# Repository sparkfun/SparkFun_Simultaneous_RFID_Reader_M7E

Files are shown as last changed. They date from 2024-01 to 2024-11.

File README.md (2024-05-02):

SparkFun Simultaneous RFID Reader - M7E Hecto
============================================

[SparkFun Simultaneous RFID Reader - M7E Hecto

[*SparkFun Simultaneous RFID Reader - M7E Hecto*](https://www.sparkfun.com/products/24738)

The SparkFun Simultaneous RFID Reader - M7E Hecto features M7E-HECTO UHF RFID reader from JADAK<sup>&copy;</sup>. We loved the capabilities of the previous version of this RFID reader, the M6E, so we created this design featuring the M7E with an on-board USB-C connector and CH340C USB to UART converter to quickly connect the board to a computer and read tags with no soldering required.

Along with the USB-C connector, the Simultaneous RFID Reader 3.3V has a 0.1"-spaced PTH header for connecting it to an external converter or to a 3.3V microcontroller of your choice to use it with the SparkFun Simultaneous RFID Tag Reader Library. A 2-way switch on the board allows for easy switching between the included communication interfaces.

Repository Contents
-------------------

* **/Documents** - Datasheets, additional product information 
* **/Hardware** - Eagle design files (.brd, .sch)
* **/Production** - Production panel files (.brd)
* **/docs** - Documentation files for the SparkFun Simultaneous RFID Reader - M7E Hecto

Documentation
--------------
* **[Hookup Guide](https://sparkfun.github.io/SparkFun_Simultaneous_RFID_Reader_M7E)** - Basic hookup guide for the SparkFun Simultaneous RFID Reader - M7E Hecto.
* **[SparkFun Simultaneous RFID Tag Reader Library](https://github.com/sparkfun/SparkFun_Simultaneous_RFID_Tag_Reader_Library)** - Arduino library for SparkFun Simultaneous RFID Readers.

Product Versions
----------------
* [WRL-24738](https://www.sparkfun.com/products/24738) - Initial release

License Information
-------------------

This product is _**open source**_! 

Please review the LICENSE.md file for license information. 

If you have any questions or concerns on licensing, please contact technical support on our [SparkFun forums](https://forum.sparkfun.com/viewforum.php?f=152).

Distributed as-is; no warranty is given.

- Your friends at SparkFun.

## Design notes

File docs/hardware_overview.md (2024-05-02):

---
icon: material/cog
---

In this section we'll take a closer look at the hardware present on the Simultaneous RFID Reader 3.3V.

## M7E Hecto UHF RFID Reader

The M7E Hecto is an Ultra-High Frequency (UHF) RFID reader capable of reading multiple tags simultaneously at up to 150 tags per second. 

<figure markdown>
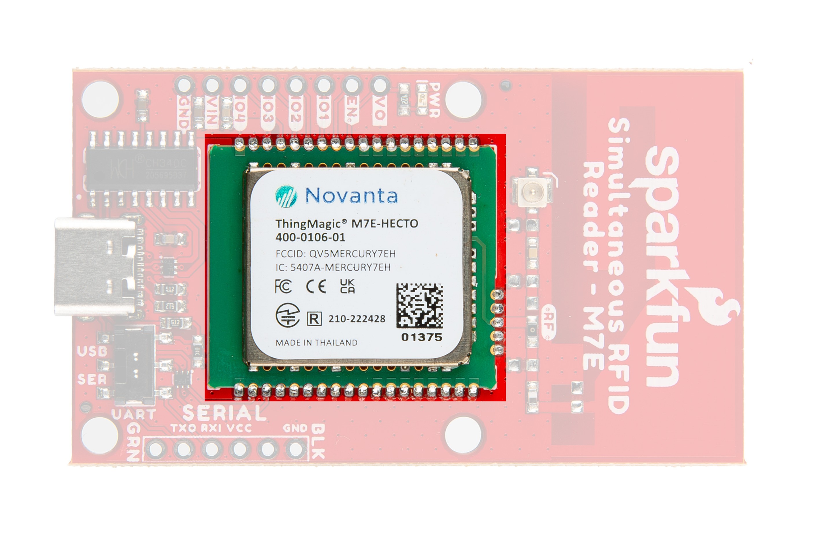
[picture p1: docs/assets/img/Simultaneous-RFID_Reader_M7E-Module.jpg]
Photo highlighting the M7E Hecto

</figure>

The module can also write data quickly to RFID tags with 96-bit EPC (80msec typical write time). The M7E Hecto boasts adjustable read and write RF power levels from 0dBm to 27dBm in 0.01dBm steps and can read tags from several feet away (even more than 16 feet in our testing!) with the proper antenna, conditions and device settings. The M7E-Hecto works with common, low-cost, passive, Gen2 UHF tags available from a variety of online vendors in a variety of shapes and sizes. We offer two types of UHF tags, ones [with adhesive](https://www.sparkfun.com/products/20228) backing and [ultra-small](https://www.sparkfun.com/products/16464) ones. Both have 64 bytes of user-writable memory.

The M7E accepts a supply voltage between <b>3.3V</b> and <b>5.5V</b> and operates normally so long as the module's current draw is below <b>1A</b> as it includes a built-in protection circuit that allows no more than <b>1A</b> drawn to prevent damage to the M7E. Therefore, it's recommended to power the M7E with a 5V source to avoid hitting the current limit at higher read/write powers or when the GPIO and Vout lines are supplying current to other devices. Refer to section 5.2 of the [M7E User Guide](./assets/component_documentation/M7E_HECTO_User_Guide.pdf) for detailed information on this limit as well as graphs showing typical current draw at various supply voltages as well as power requirements for different power settings.

## Communication Interfaces

The board has two options for interacting with the M7E Hecto's serial interface: USB-C and a plated through-hole (PTH) header. The PTH header can connect to a microcontroller or serial converter (running at <b>3.3V</b> logic or properly level-shifted). The selection switch on the board labeled <b>UART</b> allows users to choose between the two serial interface options. The board also breaks out several of the M7E Hecto's GPIO pins and the Enable pin.

<figure markdown>
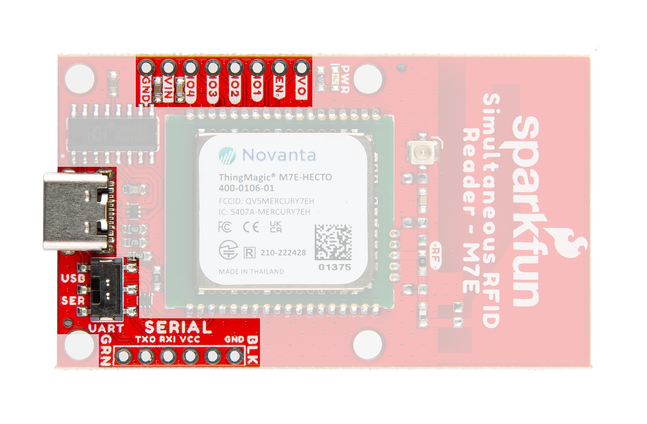
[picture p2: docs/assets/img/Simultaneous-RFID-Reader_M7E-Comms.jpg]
Photo highlighting USB, PTHs and UART Switch.

</figure>

### USB-C

The USB-C connector on the board allows for quick use of the M7E Hecto with just a USB-C cable. The board uses a CH340C USB-to-Serial adapter to translate between the M7E's UART and the USB-C connection. 

<div class="alert alert-warning">
    <b>Heads Up!</b> With RF power level set to 27dBm the board can draw over <b>700mA (3.6W @ 5V)</b>. Most USB ports on computers only source up to ~500mA so the board may start to brown out at power settings over 22dBm when powered from a USB port. Users who wish to set the over 22dBm should make sure their power source (either from USB-C via a power adapter or through a regulated <b>5V</b> supply to the VIN PTH pin) can source enough current to power the board. We recommend a power adapter like <a href="https://www.sparkfun.com/products/15448">this</a>.
</div>

### Through-Hole Serial Connection

The board includes a PTH header for serial communication with a 3.3V microcontroller or other device. The header matches the pinout for our [Serial Breakouts](https://www.sparkfun.com/products/15096) for easy connection to those devices.

### Serial Selection Switch

The two-way switch on the board labled <b>UART</b> allows the user to toggle between the two serial interfaces: USB-C (<b>USB</b>) and the Serial Header (<b>SER</b>).

### Enable and GPIO PTHs

The M7E uses an internal DC to DC converter to provide itself with power. When the <b>EN</b> (enable) pin is pulled low the DC/DC converter is turned off and the module does a hard reset. <b>EN</b> can be left unconnected for normal operation. 

!!! warning
    <b>Note:</b> The <b>3.3V</b> pin on this header is not intended as a power source. It connects to the <b>V_OUT</b> pin on the M7E Hecto which can only supply <b>5mA</b>. It is best used as a voltage reference.

## Power LED

The lone LED on the board indicates device power status. Users can disable this LED by severing the <b>PWR</b> jumper. The Power LED receives voltage from the <b>VOUT</b> pin on the M7E Hecto. Driving the <b>EN</b> pin low disables <b>VOUT</b> and can be used to turn this LED off.

<figure markdown>
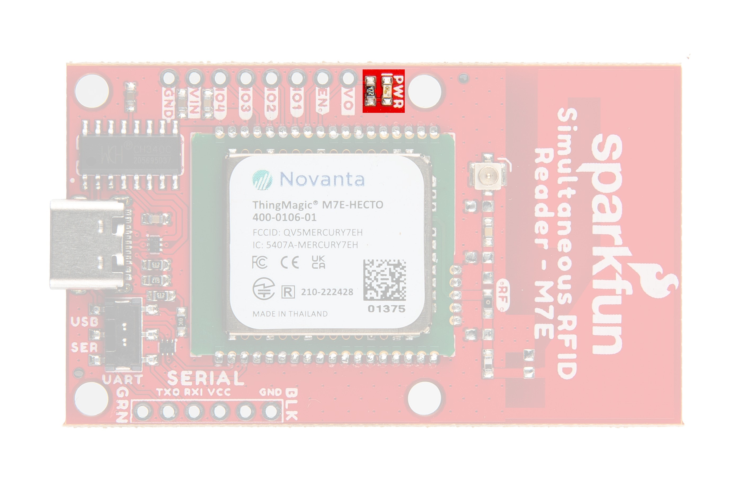
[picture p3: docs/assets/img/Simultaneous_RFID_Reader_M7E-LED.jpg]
Photo highlighting Power LED.

</figure>

## Solder Jumpers

The board has three solder jumpers labeled: <b>PWR</b>, <b>VIN SEL</b>, and <b>SHLD</b>. The table below outlines their label, function, default state, and any notes regarding their use.

<figure markdown>
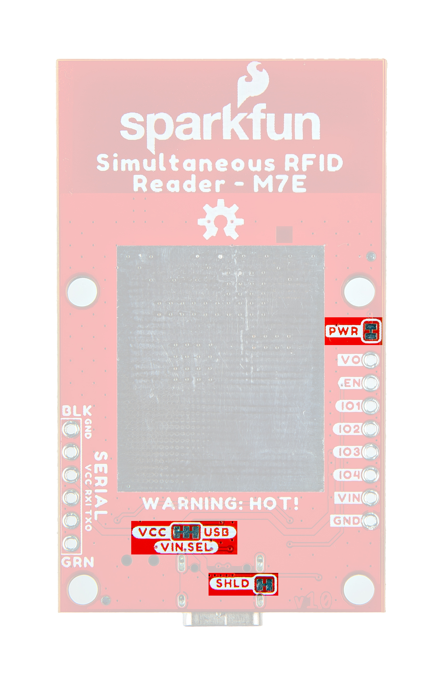
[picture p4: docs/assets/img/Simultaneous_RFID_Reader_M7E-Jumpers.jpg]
Photo highlighting solder jumpers

</figure>

<table>
    <tr>
        <th>Label</th>
        <th>Default State</th>
        <th>Function</th>
        <th>Notes</th>
    </tr>
    <tr>
        <td>PWR</td>
        <td>CLOSED</td>
        <td>Completes Power LED circuit.</td>
        <td>Open to disable Power LED.</td>
    </tr>
    <tr>
        <td>VIN SEL</td>
        <td>CLOSED</td>
        <td>Nets V_USB, VIN, and VCC together.</td>
        <td>Three-way jumper that nets all voltage inputs together. Adjust to isolate any of these voltages from the others (or all three) if needed.</td>
    </tr>
    <tr>
        <td>SHLD</td>
        <td>CLOSED</td>
        <td>Ties USB Shield pin to PCB ground plane.</td>
        <td>Open to isolate the USB Shield pin from the rest of the board.</td>
    </tr>
</table>

## Ground Plane Heatsink

The board has a large ground plane heatsink on the bottom to help dissipate heat generated by the module.

<figure markdown>
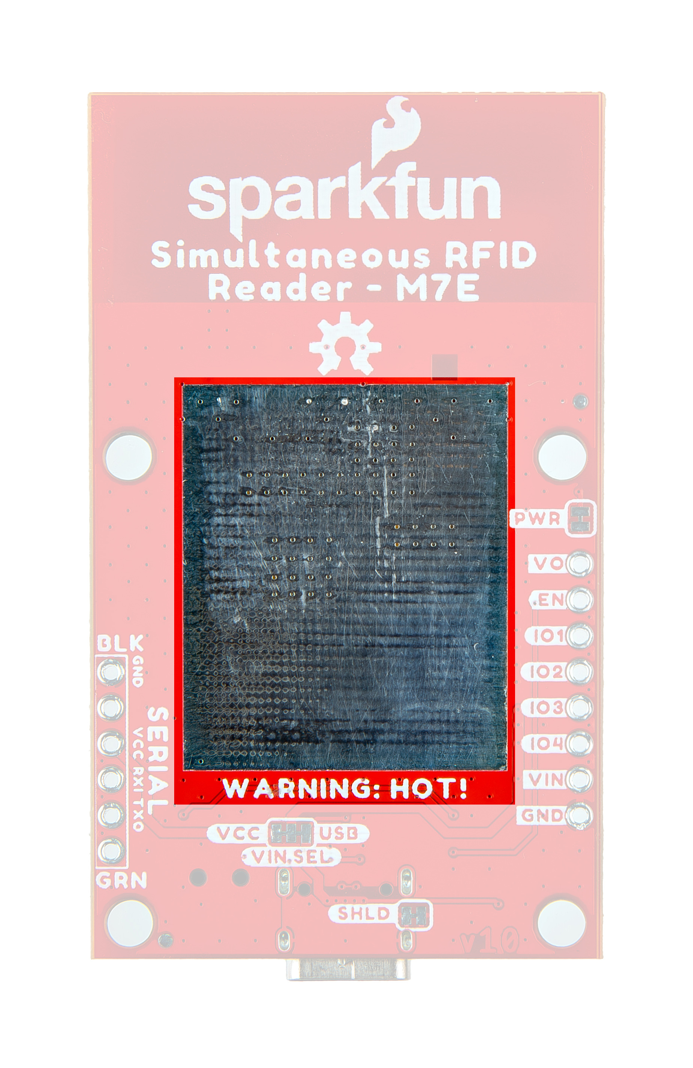
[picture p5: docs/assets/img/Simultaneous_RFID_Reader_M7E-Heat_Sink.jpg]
Photo highlighting heatsink.

</figure>

The exposed copper pour allows the connection to a heatsink such as a chassis or block of metal if needed. The M7E has an integrated temperature sensor that will monitor the internal temperature and can disable RF if the module is overheating and keeps it off until the recorded temperature drops back into the safe range (-40&deg;C to +60&deg;C). Attaching a heat sink to the exposed copper pour or adjusting the read power and/or duty cycle can help dissipate heat to prevent this throttling in long-period applications of this board. Refer to the [thermal management considerations](../thermal_management) of this guide or section 5.4 of the [M7E User Guide](./assets/component_documentation/M7E_HECTO_User_Guide.pdf) for more information.

## Antenna Options

The Hecto M7E is a powerful transmitter capable of outputting up to 27dBm! That's a lot. The board comes with a PCB trace antenna and a u.FL connector for an external antenna connection.

<figure markdown>
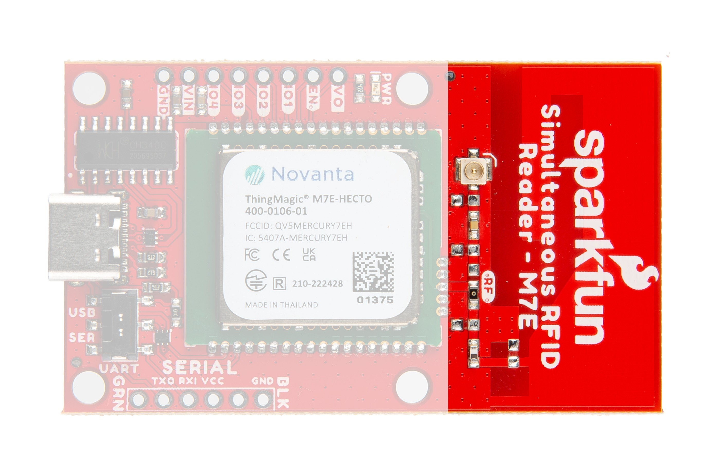
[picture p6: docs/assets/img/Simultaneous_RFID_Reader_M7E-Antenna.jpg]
Photo highlighting the PCB antenna.

</figure>

The trace antenna is enabled by default. Adjust the <b>RF</b> resistor to switch the antenna signal to the u.FL connector to use an external antenna. Refer to the [Using an External Antenna](../external_antenna) section of this guide for more information on this assembly step.

## Board Dimensions

The board measures 2.40" x 1.40" (60.96mm x 35.56mm) and has four mounting holes that fit a [4-40](https://www.sparkfun.com/products/10453) screw.

<figure markdown>
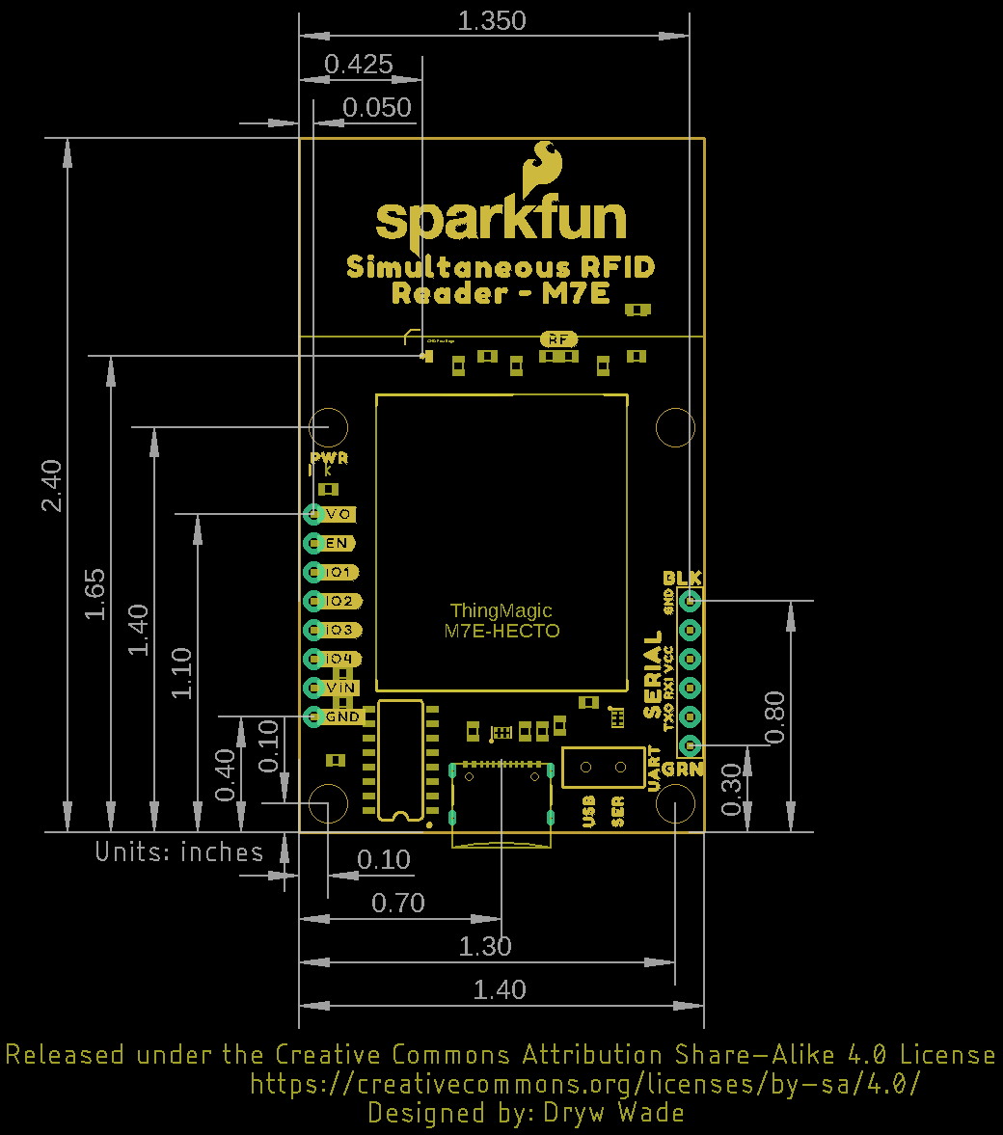
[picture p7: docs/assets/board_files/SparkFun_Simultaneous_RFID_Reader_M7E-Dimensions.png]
Board dimensions

</figure>

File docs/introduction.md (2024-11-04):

---
icon: material/book-open-page-variant
---

<div class="grid cards desc" markdown>

-   <a href="https://www.sparkfun.com/products/24738">
    **SparkFun Simultaneous RFID Reader - M7E Hecto**<br>
    **SKU:** WRL-24738

    ---

    <figure markdown>
    SparkFun Simultaneous RFID Reader - M7E Hecto
    </figure></a>

    <center>
    <article class="video_desc">
    <iframe src="https://www.youtube.com/embed/ITT54OnKUzM" title="Product Showcase: SparkFun Simultaneous RFID Reader - M7E" frameborder="0" allow="accelerometer; autoplay; clipboard-write;encrypted-media; gyroscope; picture-in-picture" allowfullscreen></iframe>
    </article>
    </center>

-   The M7E Hecto is a Ultra-High Frequency (UHF) RFID reader from JADAK<sup>&copy;</sup> capable of reading multiple tags simultaneously at up to 150 tags per second and can also write data to tags. The M7E Hecto can read tags from several feet away (up to 16 feet in our testing!) with the proper antenna, conditions and device settings. This board includes a USB-C connector and CH340C USB to UART converter to quickly connect the board to a computer and read tags with no soldering required.

    Along with the USB-C connector, the Simultaneous RFID Reader 3.3V has a 0.1"-spaced PTH header for connecting it to an external converter or to a 3.3V microcontroller of your choice to use it with the SparkFun Simultaneous RFID Tag Reader Library. A 2-way switch on the board allows for easy switching between the included communication interfaces.

    <center>
    [Purchase from SparkFun :fontawesome-solid-cart-plus:](https://www.sparkfun.com/products/24738){ .md-button .md-button--primary }
    </center>

</div>

In this guide we'll cover everything you need to set up this RFID reader and use it with the Universal Reader Assistant application to read and write to UHF tags. We'll also cover how to set this board up in a circuit with a 3.3V microcontroller and point you to where you can get started using the SparkFun Simultaneous RFID Tag Reader Arduino Library.

### Required Materials

We designed this version of the Simultaneous RFID Reader to work over either USB-C or a serial plated through-hole (PTH) connection so depending on your application, you may need different materials. 

#### USB Connection

The quickest way to get the RFID Reader up and running is through the USB-C connector. If you opt for this you'll need a USB-C cable like the ones below:

<div class="grid cards" markdown>

-   <a href="https://www.sparkfun.com/products/14743">

    <figure markdown>
    USB 3.1 Cable A to C - 3 Foot
    </figure>
    </a>
    ---
    <a href="https://www.sparkfun.com/products/14743">
    **USB 3.1 Cable A to C - 3 Foot**<br>
    CAB-14743
    </a>

-   <a href="https://www.sparkfun.com/products/15424">
    
    <figure markdown>
    Reversible USB A to C Cable - 2m
    </figure>
    </a>
    ---
    <a href="https://www.sparkfun.com/products/15424">
    **Reversible USB A to C Cable - 2m**<br>
    CAB-15424
    </a>

-   <a href="https://www.sparkfun.com/products/15425">

    <figure markdown>
    Reversible USB A to C Cable - 0.8m
    </figure>
    </a>
    ---
    <a href="https://www.sparkfun.com/products/15425">
    **Reversible USB A to C Cable - 0.8m**</br>
    CAB-15425
    </a>

-   <a href="https://www.sparkfun.com/products/15426">

    <figure markdown>
    Reversible USB A to C Cable - 0.3m
    </figure>
    </a>
    ---
    <a href="https://www.sparkfun.com/products/15426">
    **Reversible USB A to C Cable - 0.3m**<br>
    CAB-15426
    </a>

</div>

#### PTH Serial Connection

Users who prefer to use the PTH headers to connect to a serial converter or microcontroller will want to solder either wire or a set of header pins to the board to make connections to the external device. If you don't have wire, header pins or soldering tools you may want to add the products below to your cart:

!!! warning "Logic Levels"
    <b>Note:</b> The serial output on the Simultaneous RFID Reader - M7E  operates at <b>3.3V logic</b> so make sure the microcontroller or serial converter connected to this interface operates at <b>3.3V</b> or are properly level-shifted.

<div class="grid cards" markdown>

-   <a href="https://www.sparkfun.com/products/15096">

    <figure markdown>
    SparkFun Serial Basic Breakout - CH340C and USB-C
    </figure>
    </a>
    ---
    <a href="https://www.sparkfun.com/products/15096">
    **SparkFun Serial Basic Breakout - CH340C and USB-C**<br>
    DEV-15096
    </a>

-   <a href="https://www.sparkfun.com/products/9873">

    <figure markdown>
    SparkFun FTDI Basic Breakout - 3.3V
    </figure>
    </a>
    ---
    <a href="https://www.sparkfun.com/products/9873">
    **SparkFun FTDI Basic Breakout - 3.3V**<br>
    DEV-09873
    </a>

-   <a href="https://www.sparkfun.com/products/19177">

    <figure markdown>
    SparkFun IoT RedBoard - ESP32 Development Board
    </figure>
    </a>
    ---
    <a href="https://www.sparkfun.com/products/19177">
    **SparkFun IoT RedBoard - ESP32 Development Board**<br>
    DEV-19177
    </a>

-   <a href="https://www.sparkfun.com/products/15444">

    <figure markdown>
    SparkFun RedBoard Artemis
    </figure>
    </a>
    ---
    <a href="https://www.sparkfun.com/products/15444">
    **SparkFun RedBoard Artemis**<br>
    DEV-15444
    </a>

-   <a href="https://www.sparkfun.com/products/14456">

    <figure markdown>
    Soldering Iron - 60W (Adjustable Temperature)
    </figure>
    </a>
    ---
    <a href="https://www.sparkfun.com/products/14456">
    **Soldering Iron - 60W (Adjustable Temperature)**<br>
    TOL-14456
    </a>

-   <a href="https://www.sparkfun.com/products/9325">

    <figure markdown>
    Solder Lead Free - 100-gram Spool
    </figure>
    </a>
    ---
    <a href="https://www.sparkfun.com/products/9325">
    **Solder Lead Free - 100-gram Spool**<br>
    TOL-09325
    </a>

-   <a href="https://www.sparkfun.com/products/11375">

    <figure markdown>
    Hook-Up Wire - Assortment (Stranded, 22 AWG)
    </figure>
    </a>
    ---
    <a href="https://www.sparkfun.com/products/11375">
    **Hook-Up Wire - Assortment (Stranded, 22 AWG)**<br>
    PRT-11375
    </a>

-   <a href="https://www.sparkfun.com/products/553">

    <figure markdown>
    Break Away Male Headers - Right Angle
    </figure>
    </a>
    ---
    <a href="https://www.sparkfun.com/products/553">
    **Break Away Male Headers - Right Angle**<br>
    SKU
    </a>

</div>

#### Additional Materials

You'll also need UHF RFID tags for the M7E Hecto to read/write. For best range performance you'll need an external antenna along with the appropriate adapter cables. We'll demonstrate how to connect the external antenna using the cables listed below:

<div class="grid cards" markdown>

-   <a href="https://www.sparkfun.com/products/14131">

    <figure markdown>
    UHF RFID Antenna (RP-TNC)
    </figure>
    </a>
    ---
    <a href="https://www.sparkfun.com/products/14131">
    **UHF RFID Antenna (RP-TNC)**<br>
    WRL-14131
    </a>

-   <a href="https://www.sparkfun.com/products/18569">

    <figure markdown>
    RP-SMA to U.FL Cable - 150mm
    </figure>
    </a>
    ---
    <a href="https://www.sparkfun.com/products/18569">
    **RP-SMA to U.FL Cable - 150mm**<br>
    WRL-18569
    </a>

-   <a href="https://www.sparkfun.com/products/20226">

    <figure markdown>
    UHF RFID Tags - 30mm x 16mm (Adhesive)
    </figure>
    </a>
    ---
    <a href="https://www.sparkfun.com/products/20226">
    **UHF RFID Tags - 30mm x 16mm (Adhesive)**<br>
    WRL-20226
    </a>

-   <a href="https://www.sparkfun.com/products/14132">

    <figure markdown>
    Interface Cable for RP-TNC to RP-SMA - 1m
    </figure>
    </a>
    ---
    <a href="https://www.sparkfun.com/products/14132">
    **Interface Cable for RP-TNC to RP-SMA - 1m**<br>
    CAB-14132
    </a>

</div>

### Suggested Reading

If you aren't familiar with the following concepts, we recommend reading through these tutorials before continuing with this guide.

<div class="grid cards hide col-4" markdown align="center">

-   <a href="https://learn.sparkfun.com/tutorials/8">
    <figure markdown>
    Serial Communication
    </figure>
    </a>
    <a href="https://learn.sparkfun.com/tutorials/8">**Serial Communication**
    </a>

-   <a href="https://learn.sparkfun.com/tutorials/62">
    <figure markdown>
    Logic Levels
    </figure>
    </a>
    <a href="https://learn.sparkfun.com/tutorials/62">**Logic Levels**
    </a>

-   <a href="https://learn.sparkfun.com/tutorials/633">
    <figure markdown>
    RFID Basics
    </figure>
    </a>
    <a href="https://learn.sparkfun.com/tutorials/633">**RFID Basics**
    </a>

-   <a href="https://learn.sparkfun.com/tutorials/61">
    <figure markdown>
    Installing Arduino IDE
    </figure>
    </a>
    <a href="https://learn.sparkfun.com/tutorials/61">**Installing Arduino IDE**
    </a>

-   <a href="https://learn.sparkfun.com/tutorials/15">
    <figure markdown>
    Installing an Arduino Library
    </figure>
    </a>
    <a href="https://learn.sparkfun.com/tutorials/15">**Installing an Arduino Library**
    </a>

-   <a href="https://learn.sparkfun.com/tutorials/112">
    <figure markdown>
    Serial Terminal Basics
    </figure>
    </a>
    <a href="https://learn.sparkfun.com/tutorials/112">**Serial Terminal Basics**
    </a>

-   <a href="https://learn.sparkfun.com/tutorials/845">
    <figure markdown>
    Three Quick Tips About Using U.FL
    </a>
    <a href="https://learn.sparkfun.com/tutorials/845">**Three Quick Tips About Using U.FL**
    </a>

-   <a href="https://learn.sparkfun.com/tutorials/664">
    <figure markdown>
    How to Work with Jumper Pads and PCB Traces
    </figure>
    </a>
    <a href="https://learn.sparkfun.com/tutorials/664">**How to Work with Jumper Pads and PCB Traces**
    </a>
</div>

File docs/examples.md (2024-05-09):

---
icon: simple/arduino
---

Let's take an in-depth look at most of the examples included in the SparkFun Simultaneous RFID Reader Arduino Library.

## UART Switch Position & Software Serial

Make sure the Serial Selection Switch is in the <b>"SER"</b> position when using this library. All of the examples in this Arduino library use the [Software Serial Library](https://docs.arduino.cc/learn/built-in-libraries/software-serial/) so if you are not using the SparkFun RedBoard IoT and following the assembly instructions in the Hardware Assembly section, make sure to connect the RX/TX pins on the SER header to compatible pins on your chosen development board. Note, this library 

## Code to Note

The latest version of the Simultaneous RFID Reader Library has a couple of settings to take note of and adjust accordingly depending on your hardware and setup.

### Serial Selection (Software vs Hardware)

If you're using a development board that supports [Software Serial](https://docs.arduino.cc/learn/built-in-libraries/software-serial/), uncomment the following lines and adjust the pins for RX/TX if necessary:

``` c++
#include <SoftwareSerial.h>
SoftwareSerial softSerial(2, 3); //RX, TX
```

The next option selects which type of serial is used. The code lists a couple of examples for both software serial and hardware so adjust the definition as needed. For example, if you're using a software serial library, define this as `softserial`. If you're using a hardware serial port on your development board, select the serial port (eg. Serial1) as shown below: 

``` c++
// #define rfidSerial softSerial // Software serial (eg. Arudino Uno or SparkFun RedBoard)
#define rfidSerial Serial1 // Hardware serial (eg. ESP32 or Teensy)
```

### Baud Rate Selection

Next, you'll want to define the baud rate for `rfidBaud`. We recommend using the settings shown below with 38400 when using software serial and 115200 when using hardware serial:

``` c++
// #define rfidBaud 38400
#define rfidBaud 115200
```

### Module Selection

Since this library supports both the M6E Nano and M7E Hecto, you'll need to define which module you are using. Adjust or comment/uncomment the `moduleType` definition to set it to the correct module:

``` c++
// #define moduleType ThingMagic_M6E_NANO
#define moduleType ThingMagic_M7E_HECTO
```

## Example 1 - Constant Read

The first example sets the M7E to constantly scan and report any tags it sees in the vicinity. Open the example by navigating to **File > Examples > SparkFun Simultaneous RFID Reader Library > Example 1 Constant Read**. Select your Board and Port and click the "Upload" button. Once the code finishes uploading, open the [serial monitor](https://learn.sparkfun.com/tutorials/terminal-basics/arduino-serial-monitor-windows-mac-linux) with the baud set to **115200**. 

??? "Example 1 - Constant Read"

    ```
	--8<-- "https://raw.githubusercontent.com/sparkfun/SparkFun_Simultaneous_RFID_Tag_Reader_Library/master/examples/Example1_Constant_Read/Example1_Constant_Read.ino"
	```

The code attempts to set up the module with the defined baud rate and if that fails, it prints "Module failed to respond. Please check wiring" If you see this prompt, double-check your connections to your development board and retry. On successful module startup and setup, the code prints "Press a key to begin scanning for tags." Send any key message and the M7E will begin to scan for any tags in range and print out their EPC as the screenshot below shows:

<figure markdown>
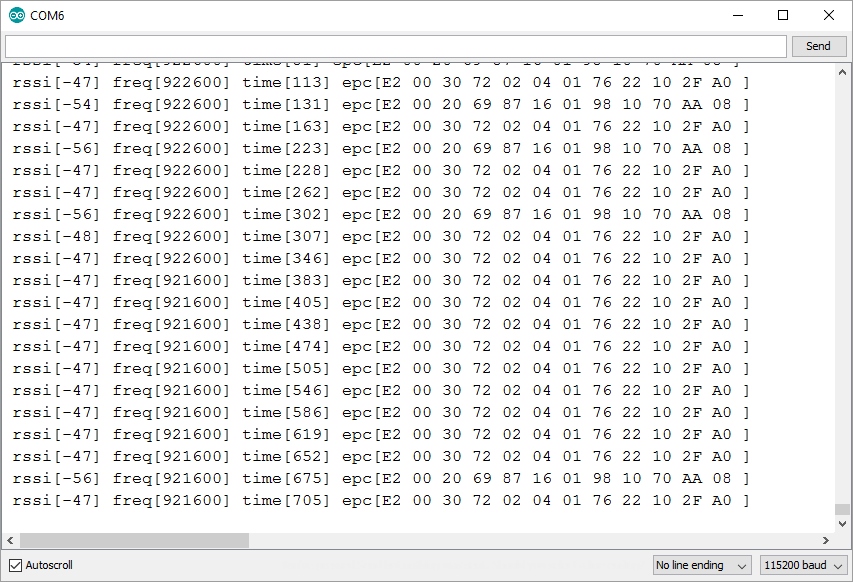
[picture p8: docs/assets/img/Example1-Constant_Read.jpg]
Screenshot of serial printout of tags read.

</figure>

## Example 2 - Read EPC

The second example demonstrates how to perform a single-shot read of one tag in the reader's range and print out the EPC value over serial. This example uses the `.readTagEPC()` function to pass it an array of bytes (in almost all cases EPCs are 12 bytes), the size of the array (12), and the amount of time to scan before giving up (500ms is default). This returns **RESPONSE_SUCCESS** when the M7E detects a tag and stores the EPC in the array given.

??? "Example 2 - Read EPC"

    ```
    --8<-- "https://raw.githubusercontent.com/sparkfun/SparkFun_Simultaneous_RFID_Tag_Reader_Library/master/examples/Example2_Read_EPC/Example2_Read_EPC.ino"
    ```

<figure markdown>
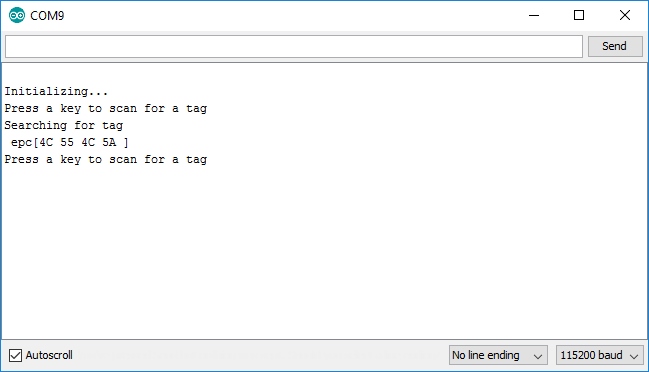
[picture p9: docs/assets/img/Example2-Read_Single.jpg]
Screenshot of successful tag read with EPC printout.

</figure>

Note, this example also includes definitions and code to set up and use the buzzer found on the [Simultaneous RFID Reader - M6E Nano](https://www.sparkfun.com/products/14066) which is not present on the Simultaneous RFID Reader - M7E though users can wire a buzzer like [this](https://www.sparkfun.com/products/12567) for an audio feedback when a tag is scanned.

## Example 3 - Write EPC

Example 3 shows how to write a character string and store it as a custom EPC value. This is a great way to keep track of which tag is which by setting the EPC to something like `WRENCH` or `PILL#317`. Note, EPCs can only be written in an even number of bytes like the example sets it to:

??? "Example 3 - Write EPC"

    ```
    --8<-- "https://raw.githubusercontent.com/sparkfun/SparkFun_Simultaneous_RFID_Tag_Reader_Library/master/examples/Example3_Write_EPC/Example3_Write_EPC.ino"
    ```

``` c++
char stringEPC[] = "Hello!"; //You can only write even number of bytes
byte responseType = nano.writeTagEPC(stringEPC, sizeof(stringEPC) - 1); //The -1 shaves off the \0 found at the end of string
```
This example also introduces a new function `setWritePower()`. This sets the power level when writing to a tag similar to `setReadPower` so it can be boosted up to the same values as read power.

``` c++
nano.setWritePower(500); //5.00 dBm. Higher values may cause USB port to brown out
//Max Write TX Power is 27.00 dBm and may cause temperature-limit throttling
```

## Examples 4 & 5 - Read/Write User Data

Example 4 shows how to detect and read a tag's available user memory. Not all UHF RFID tags have user memory and may not be configurable.

??? "Example 4 - Read User Data"

    ```
    --8<-- "https://raw.githubusercontent.com/sparkfun/SparkFun_Simultaneous_RFID_Tag_Reader_Library/master/examples/Example4_Read_User_Data/Example4_Read_User_Data.ino"
    ```

Example 5 demonstrates how to edit a tag's user data through the `.writeUserData()` function. This function lets you pass an array of characters to the function and records it to the first tag detected by the reader. 

??? "Example 5 - Write User Data"

    ```
    --8<-- "https://raw.githubusercontent.com/sparkfun/SparkFun_Simultaneous_RFID_Tag_Reader_Library/master/examples/Example5_Write_User_Data/Example5_Write_User_Data.ino"
    ```

``` c++
char testData[] = "ACBD"; //Must be even number of bytes. "Hello" is recorded as "Hell".
byte responseType = nano.writeUserData(testData, sizeof(testData) - 1); //The -1 shaves off the \0 found at the end of string
```

<figure markdown>
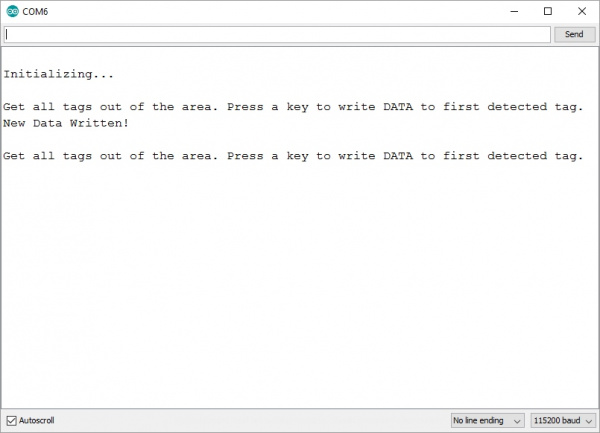
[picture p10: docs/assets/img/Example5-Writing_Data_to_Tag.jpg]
Screenshot of successful write to user data.

</figure>

A few bytes of editable memory may not sound like a lot be remember these are passive tags - no batteries required! You can query a tag for the user's dietary restrictions. Or you could adjust the lighting depending on who walked in the room. Or you could set the time at which a medication must be taken. Perhaps a prosthetic leg goes into a more aggressive mode when basketball shorts are worn. 

## Examples 6, 7, 8 - Passwords

The next three examples all deal with passwords to lock a tag with an Access Password or disable a tag with a Kill Password. 

**Example 6 - Read Passwords** displays the Access and Kill passwords for a tag detected by the reader. The Access password allows a user to lock a tag, preventing modification of various parts of the memory (EPC, User, etc). The Kill password is needed to disable a tag. Both passwords are `0x00000000` by default. 

??? "Example 6 - Read Passwords"

    ```
    --8<-- "https://raw.githubusercontent.com/sparkfun/SparkFun_Simultaneous_RFID_Tag_Reader_Library/master/examples/Example6_Read_Passwords/Example6_Read_Passwords.ino"
    ```

<figure markdown>
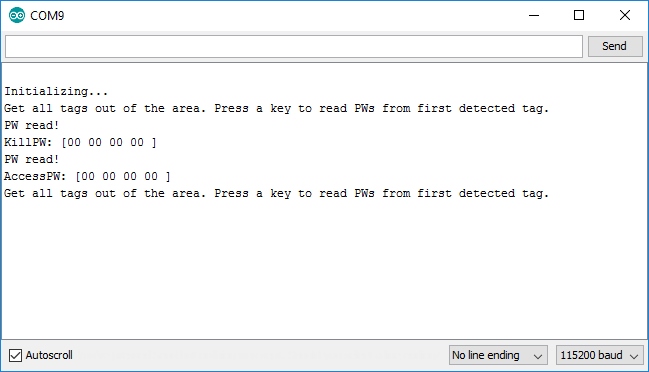
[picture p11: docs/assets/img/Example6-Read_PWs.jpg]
Screenshot showing serial printout of access and kill passwords

</figure>

**Example 7 - Write Passwords** shows you how to write new passwords for both Access and Kill. 

??? "Example 7 - Write Passwords"

    ```
    --8<-- "https://raw.githubusercontent.com/sparkfun/SparkFun_Simultaneous_RFID_Tag_Reader_Library/master/examples/Example7_Write_Passwords/Example7_Write_Passwords.ino"
    ```

These values can be adjusted from the passwords set in the example by changing the following lines for myKillPW and myAccessPW:

``` c++
byte myKillPW[] = {0xEE, 0xFF, 0x11, 0x22};

byte myAccessPW[] = {0x12, 0x34, 0x56, 0x78};
```

<figure markdown>
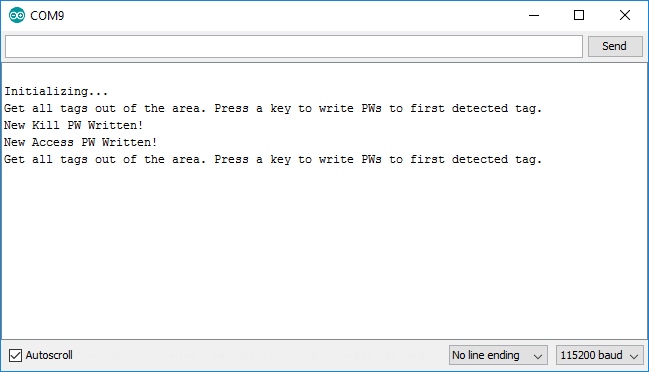
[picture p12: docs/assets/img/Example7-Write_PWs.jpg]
Screenshot showing successful password writes.

</figure>

After running Example 7, re-run Example 6 to see the updated passwords and ensure they are correct. It may seem odd that you can view the passwords. The Gen2 protocol has quite a few methods to lock out various portions of the memory preventing them from being read. Once the Access password is set the ability to read passwords, read user memory, and read portions of the EPC can all be controlled; this is called locking. Currently, locking is not supported in the Arduino library but it is available in the URA and in the Mercury API.

**Example 8 - Kill Tag** is an interesting example. It's pretty rare that you'll need to kill a tag but we find the concept fascinating and wanted to build in support for it.

??? warning - "Danger!"

    <b>Note:</b> Killing a tag blows an internal fuse to the IC and makes the tag irreversibly dead.

??? "Example 8 - Kill Tag"

    ```
    --8<-- "https://raw.githubusercontent.com/sparkfun/SparkFun_Simultaneous_RFID_Tag_Reader_Library/master/examples/Example8_Kill_Tag/Example8_Kill_Tag.ino"
    ```

It is very good to see that the protocol has the kill feature. Killing a tag makes sense after an item has been purchased (gallon of milk) or a process has been completed (dry cleaning has been picked up). By limiting the life-span of a tag you can help protect end user privacy and tracking.

The Gen2 protocol is well written and prevents a user from walking into a Wal-Mart and blasting away all the tags that haven't been configured. The default Kill password is all 0s but any tag will ignore the kill command with the password set to 0s. Therefore, you must first write a non-zero kill password (using Example7) then you must issue the kill command using the new password.

<figure markdown>
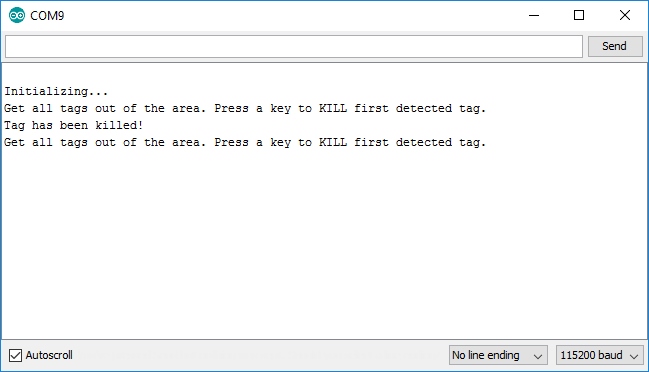
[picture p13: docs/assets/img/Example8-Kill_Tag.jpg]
Screenshot showing serial printout of tag being killed.

</figure>

If you're very paranoid about someone else using an UHF RFID reader/writer to reconfigure your tags consider writing new Access and Kill passwords to your tags then use the Universal Reader Assistant to lock the tags.

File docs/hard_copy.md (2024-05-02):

---
icon: material/book-open-variant
---

Need to download or print our hookup guide?

* [Print :fontawesome-solid-print:](../print_view) (Single-Page View)
    * To save as a `*.pdf` file, select the **Printer** or **Destination** labeled ++"Save as PDF"++. *(Instructions will vary based on the browser)*
<!-- * [Download :fontawesome-regular-file-pdf:](../hookup_guide.pdf) *(Beta - demonstration only)* -->

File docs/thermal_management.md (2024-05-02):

---
icon: material/thermometer
---

The module can reach temperatures greater than 85&deg;C (185&deg;F) when operating at full read power over extended periods so thermal management is an important consideration using this board. 

The module will automatically throttle itself to prevent permanent damage from heat. This board provides enough ground plane heatsinking to allow the module to operate at full read power for tens of minutes before throttling occurs. If you plan to operate the module at full power for extended periods (over an hour) we recommend attaching a heatsink. 

You can get the 1:1 dimensional drawing of the board [here](https://cdn.sparkfun.com/assets/f/c/d/5/3/Simultaneous_RFID_Reader_3.3V-Dimensions1.png). The dimensional drawing below shows the exposed thermal pad and mounting holes. 

<figure markdown>
Board Dimensions (https://cdn.sparkfun.com/assets/f/c/d/5/3/Simultaneous_RFID_Reader_3.3V-Dimensions1.png "Click to enlarge")
<figcaption><i>Dimensional Drawing showing the mounting holes and exposed thermal pad</i></figcaption>
</figure>

Heatsinking won’t be required in most prototyping applications. However, if you have heat-sensitive items near the module (such as temperature or humidity sensors) they may be influenced by the module. If you are planning to install the module for long-term operation we recommend attaching a heatsink with [thermal compound](https://www.sparkfun.com/products/9599) for best results.

The module also supports changing the read duty cycle to reduce heat dissipation as well. Refer to the [M7E-Hecto Design Guide](./assets/component_documentation/M7E_HECTO_User_Guide.pdf) for more information.

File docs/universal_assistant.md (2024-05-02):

The Universal Reader Assistant is a great way to start taking advantage of the full capabilities of the M7E-Hecto. Unfortunately, it's only available for Windows.

## Download & Install

Start by downloading the Universal Reader Assistant (URA). 32-bit and 64-bit versions are available.

<center>
[Universal Reader Assistant Download](https://www.jadaktech.com/product/thingmagic-universal-reader-assistant/){ .md-button .md-button--primary }
</center>

Open the installer once downloading finishes and follow the installation wizard instructions.

## Universal Reader Assistant Setup Wizard

Make sure the Simultaneous RFID Reader is plugged in either over USB or through the Serial Header to a USB-to-Serial converter with the UART selection switch in the correct position, and open the Universal Reader Assistant. You should be greeted by the Connection Wizard menu to select the reader type and port:

<figure markdown>
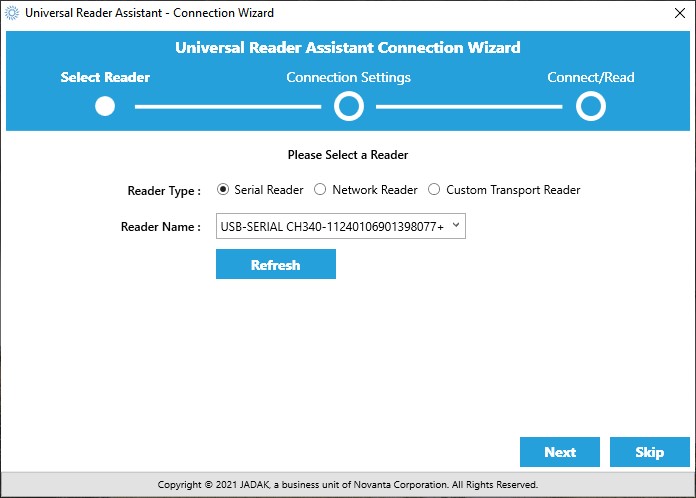
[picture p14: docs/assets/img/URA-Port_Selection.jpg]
Photo of URA Connection Wizard.

</figure>

You can skip this selection and move on to the main menu of the Universal Reader Assistant. Otherwise, select the port your Simultaneous RFID Reader is on and click "Next" and the Connection Wizard should show you the RFID reader settings:

<figure markdown>
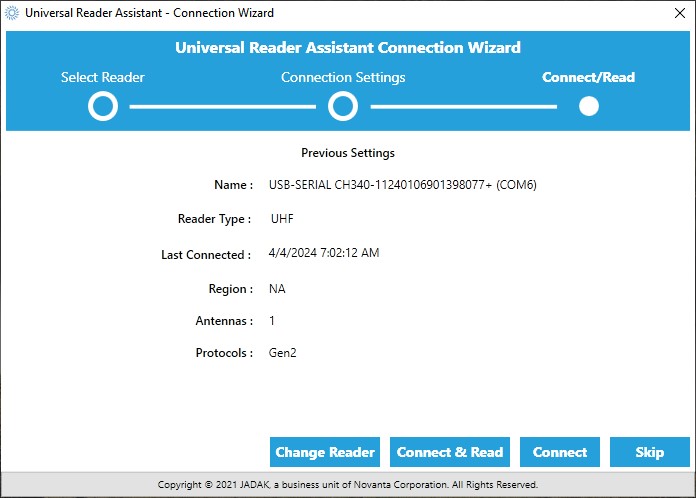
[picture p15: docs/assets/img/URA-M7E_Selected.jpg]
Photo showing connection settings with M7E selected.

</figure>

Click either "Connect & Read" or "Connect" to open up the Universal Reader Assistant main window.

## Universal Reader Assistant Main Window

The main window of the Universal Reader Assistant contains a whole bunch of settings and status menus to adjust everything from the M7E's read/write options, power level and even perform firmware updates. It also has a handy readout for the M7E's internal temperature along with multiple tabs for interacting with tags the M7E sees including simple tag data, writing to the user memory and also locking a tag with a custom password.

There are a ton of features to the M7E from ThingMagic. Poke around the Universal Reader Assistant to learn more. *Write EPC* and *User Memory* are two of the most commonly used tabs.

!!! info
    <b>Note:</b> The ‘Transport Logging’ checkbox is very handy. Select this box and all the serial communication will be recorded to a log file. These HEX bytes can be deciphered and recreated using an Arduino or other microcontroller if you need a particular capability or feature that is not supported in the SparkFun Simultaneous RFID Reader Arduino library.

### Thermal Throttling

If you see this window pop up it means the module is reporting a temperature-limit fault condition. The module has an internal temperature sensor and will protect itself from permanent damage. You’ll need to lower your read power or add heatsinking. See the previous section of this guide, Thermal Considerations, for more information.

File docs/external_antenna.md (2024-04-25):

---
icon: material/antenna
---

The integrated PCB antenna works well over short distances but users who want to get the maximum range for the M7E Hecto should consider using an external antenna. Connecting an external antenna to the Simultaneous RFID Reader - M7E requires some hardware adjustments, minor assembly steps and other considerations regarding the antenna. Let's go over these adjustments and considerations. 

## FCC Regulations

From section 5.8 of the [M7E Hecto User Guide](./assets/component_documentation/M7E_HECTO_User_Guide.pdf):

> No additional transmitter-compliance testing is required if the module is operated with the same type of antenna as listed in the FCC filing, as long as it has equal or lower gain than the antenna listed. Equivalent antennas must be of the same general type (e.g. dipole, circularly polarized patch, etc.), and must have similar in-band and out-of-band characteristics (consult specification sheet for cutoff frequencies).

The board's PCB trace antenna is a patch antenna with a much lower gain than the list of approved antennas which allows the use of an unmodified board in the field without additional FCC testing.

The **u.FL connector** allows users to connect higher-gain directional antennas. However, there are stipulations as to what external antennas can be used and **additional FCC certifications may be required**. 

!!! info
    <b>Note:</b> The onboard PCB antenna complies with the FCC regulation.

The list below from section 5.7 of the [M7E Hecto User Guide](./assets/component_documentation/M7E_HECTO_User_Guide.pdf) outlines antennas ThingMagic has tested and gotten approved by the FCC. You may use a different antenna from the ones in the list but it <b><i>must be of equal or less gain than an antenna previously authorized under the same FCC ID and must have similar in-band and out-of0band characteristics (consult specification sheet for cut-off frequencies)</i></b> if used in a product without additional testing.

<figure markdown>
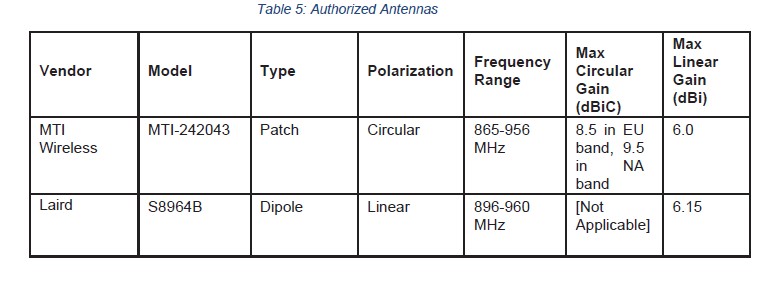
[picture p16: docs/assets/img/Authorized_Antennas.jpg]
Table of antennas

<figcaption><i>List of approved antenas</i></figcaption>
</figure>

## Attaching the External Antenna

Switching to the external antenna connection requires changing the position of the antenna (labeled RF) resistor to route the M7E's antenna signal to the u.FL connector on the board.

!!! info "Adjusting from PCB Antenna to u.FL Connection"
<b>Note: </b> You do not need an external antenna for basic use of the Simultaneous RFID Reader - M7E but the PCB antenna reads tags reliably at only up to a few inches away at the highest read power and with the PCB antenna positioned away from any solid surfaces. If you want to take advantage of the full range, follow the steps below to modify the board and enable the u.FL connector for an external antenna connection. 

If you have never worked with surface mount components, we recommend reading through these tutorials:

<div class="grid cards" markdown align="center">

-   <a href="https://learn.sparkfun.com/tutorials/how-to-use-a-hot-air-rework-station">
    <figure markdown>
    How to Use a Hot Air Rework Station
    </figure>
    </a>
    <a href="https://learn.sparkfun.com/tutorials/how-to-use-a-hot-air-rework-station">**How to Use a Hot Air Rework Station**
    </a>

-   <a href="https://learn.sparkfun.com/tutorials/how-to-solder-through-hole-soldering#advanced_smd">
    <figure markdown>
    How to Solder: Through-Hole Soldering
    </figure>
    </a>
    <a href="https://learn.sparkfun.com/tutorials/how-to-solder-through-hole-soldering#advanced_smd">**How to Solder: Through-Hole Soldering - Advanced SMD**
    </a>
</div>

Carefully reflow the 0k&ohm; resistor labeled **RF** to move it to the u.FL position. You can either use a [soldering iron](https://www.sparkfun.com/products/23913) or [hot-air rework station](https://www.sparkfun.com/products/21253) to reflow the solder holding the resistor into place. The photo below shows the RF resistor after adjusting it to the u.FL position.

<figure markdown>
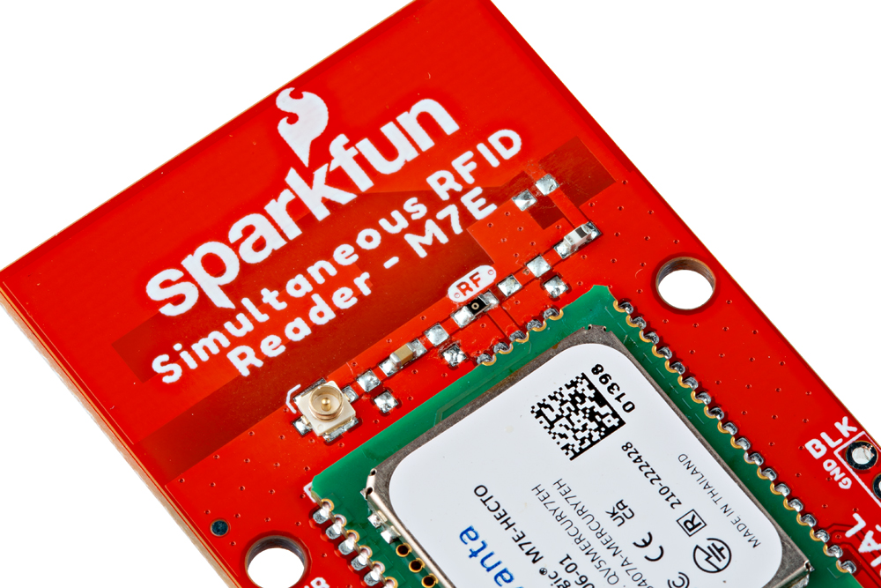
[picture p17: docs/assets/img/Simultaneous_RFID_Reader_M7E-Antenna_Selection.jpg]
Photo showing 0k ohm resistor adjusted to external antenna position.

<figcaption><i>Take careful note of the position of this resistor in the photo to make sure it is in the correct position.</i></figcaption>
</figure>

Next, attach the u.FL to the [RP-SMA connector cable](https://www.sparkfun.com/products/662). Because this connector is fragile we recommend either taping or hot gluing the sheath of the cable to the PCB. This will help prevent damage to the u.FL connector in case the cable gets pulled on.

<figure markdown>
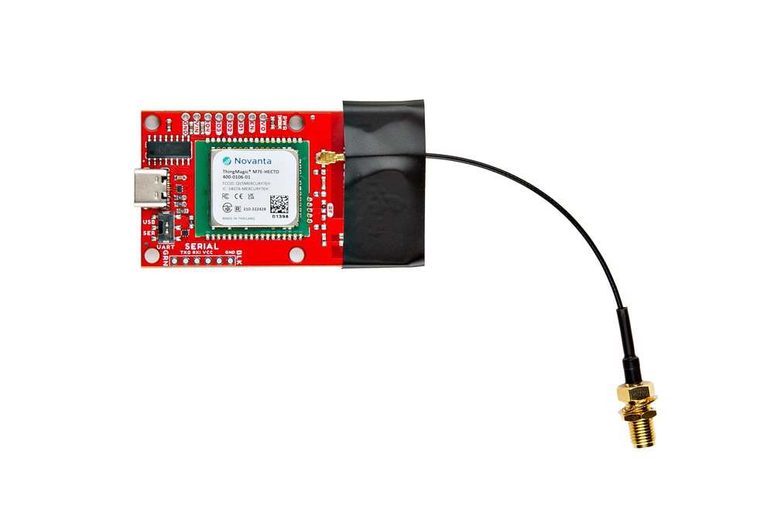
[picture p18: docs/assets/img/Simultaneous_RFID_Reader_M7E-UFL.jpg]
Photo showing u.Fl cable secured with electrical tape.

</figure>

To get the best range we recommend attaching an external high-gain antenna to a tripod of some sort. If you only have a desk, that's ok too.

<figure markdown>
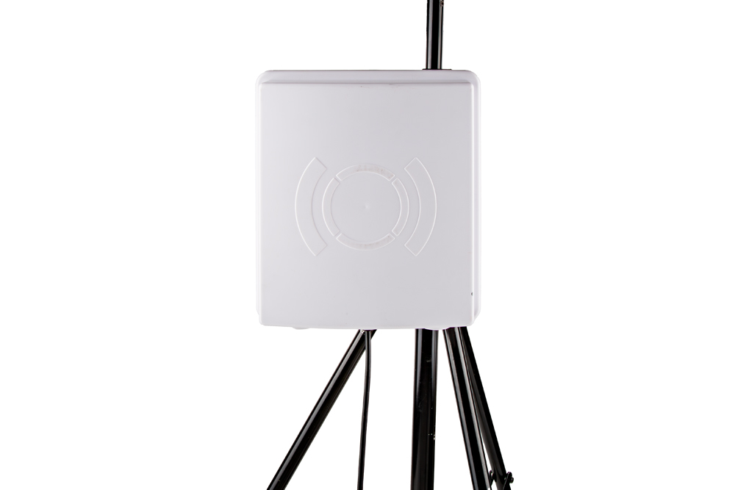
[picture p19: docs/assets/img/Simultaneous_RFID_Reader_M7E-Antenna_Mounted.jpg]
Photo showing external antenna mounted.

</figure>

We used the included hardware with the antenna to attach it to the leg of the tripod. 

<figure markdown>
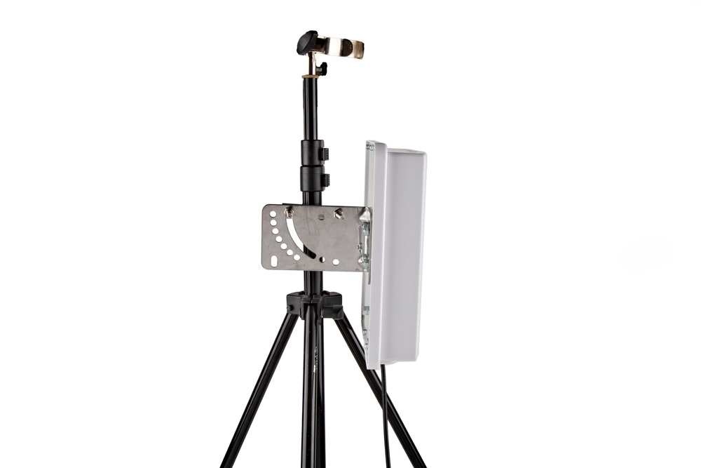
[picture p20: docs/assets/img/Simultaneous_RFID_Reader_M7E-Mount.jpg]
Photo showing antenna mounted to tripod.

</figure>

Now connect the RP-SMA to RP-TNC cable. And finally, connect the RP-TNC to the external antenna. You can use a different UHF RFID antenna but you will need to have the correct connectors and cables to go from the u.FL connector on the board to the connector on your specific antenna.

<figure markdown>
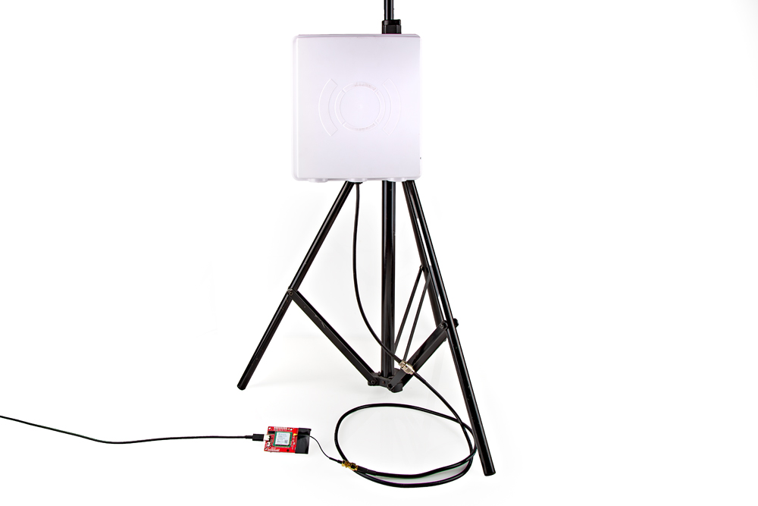
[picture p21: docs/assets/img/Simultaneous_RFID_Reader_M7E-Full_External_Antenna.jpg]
Photo showing completed external antenna assembly

</figure>

!!! warning

    <b>Don't Forget!</b> Ensure that personnel <b>do not</b> stand in the radiation beam of the antenna unless they are more than 21cm away from the face of the antenna (to adhere to FCC limits for long-term exposure). Refer to the [M7E Hecto design guide](./assets/component_documentation/M7E_HECTO_User_Guide.pdf) for more information.

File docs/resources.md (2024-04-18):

For more information about the SparkFun Simultaneous RFID Reader - M7E Hecto, check out the following resources:

* [Schematic](./assets/board_files/SparkFun_Simultaneous_RFID_Reader_M7E.pdf)
* [Eagle Files](./assets/board_files/SparkFun_Simultaneous_RFID_Reader_M7E.zip)
* [Board Dimensions](./assets/board_files/SparkFun_Simultaneous_RFID_Reader_M7E-Dimensions.png)
* [M7E Hecto User Guide](./assets/component_documentation/M7E_HECTO_User_Guide.pdf)
* [GitHub Hardware Repo](https://github.com/sparkfun/SparkFun_Simultaneous_RFID_Reader_M7E)
* [SparkFun Simultaneous RFID Reader Arduino Library](https://github.com/sparkfun/SparkFun_Simultaneous_RFID_Tag_Reader_Library)

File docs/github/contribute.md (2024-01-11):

# Contribute: Make an Augmentation!
Spot an improvement opportunity? Feel free to contribute to our open-source design and documentation. 

## :material-file-document-multiple:&nbsp;Improve our Documentation
All of this documentation can be modified by you! Please help us make it better.

* These pages are contained in the [`docs` folder](https://github.com/sparkfun/SparkFun_Simultaneous_RFID_Reader_M7E/tree/main/docs) of the [SparkFun Simultaneous RFID Reader - M7E repository](https://github.com/sparkfun/SparkFun_Simultaneous_RFID_Reader_M7E).

<!-- ### :material-source-pull:&nbsp;Submit a Correction -->
### Submit a Correction

1. With a GitHub account, [fork this repository](https://github.com/sparkfun/SparkFun_Simultaneous_RFID_Reader_M7E/fork).
2. Add your corrections or improvements to the markdown file.
3. File a pull request with your changes, and enjoy making the ~~words~~ ~~worlds~~ world a better place.
	* Once received, the documentation specialist will automatically be notified.
	* We will review your suggested improvements to make sure they are correct and fit within our documentation standards.

## :material-cog:&nbsp;Improve our Hardware Design
All of our designs are open-source! Please help us make it better.

* Our board design files are contained in the [`Hardware` folder](https://github.com/sparkfun/SparkFun_Simultaneous_RFID_Reader_M7E/tree/main/Hardware) of the [SparkFun Simultaneous RFID Reader - M7E repository](https://github.com/sparkfun/SparkFun_Simultaneous_RFID_Reader_M7E).

<!-- ### :material-source-pull:&nbsp;Submit a Design Enhancement -->
### Submit a Design Enhancement

1. With a GitHub account, [fork this repository](https://github.com/sparkfun/SparkFun_Simultaneous_RFID_Reader_M7E/fork).
2. Add your design augmentation(s)
3. File a pull request with your changes, and enjoy making the ~~words~~ ~~worlds~~ world a better place.
	1. Once received, the engineer in charge of the original design will automatically be notified.
	2. We will review your suggested improvement(s) to verify that they are within our board design standards and meet our product design requirements.
	3. If approved, we will flag these changes for our next board revision. Congrats! 🍻

		!!! info
			Even if your suggestion is accepted, these changes may not be immediately available for purchase. We may have to cycle through our current product inventory first.

## Contributors&nbsp;:clap:
Let's provide some recognition to the contributors for this project!

GitHub Contributors Image
<br>


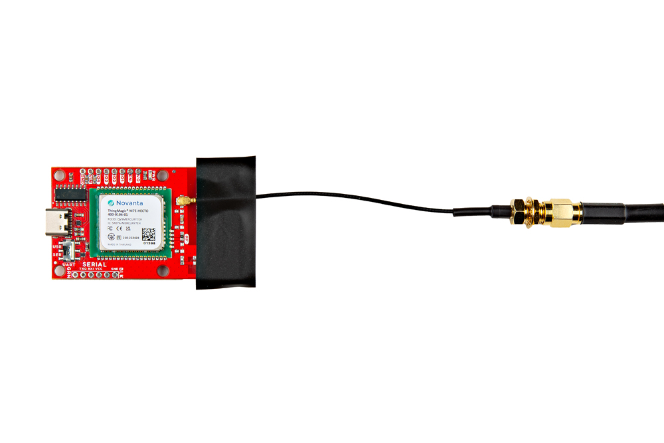
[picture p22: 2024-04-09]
docs/assets/img/Simultaneous_RFID_Reader_M7E-UFL_to_Antenna.jpg

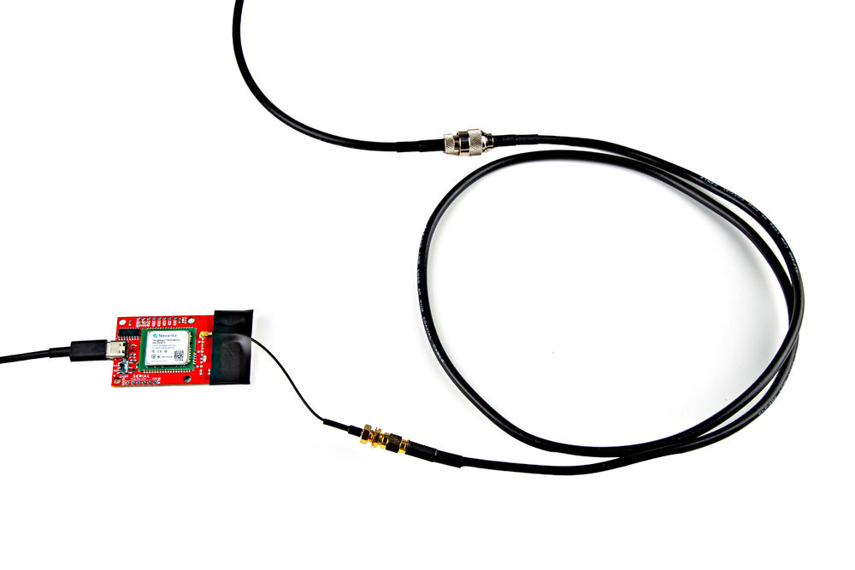
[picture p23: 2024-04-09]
docs/assets/img/Simultaneous_RFID_Reader_M7E-UFL_to_Antenna_Wire2.jpg

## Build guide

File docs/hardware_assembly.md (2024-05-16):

---
icon: material/tools
---

In this section we'll cover the two ways to set up the Simultaneous RFID Reader - M7E over both USB-C and connected to a microcontroller for use with the SparkFun Simultaneous RFID Reader Arduino Library. 

## Communicating via USB-C Serial

The fastest and easiest way to start using the board is through the USB-C connector. Simply plug the board into a computer with a USB-C cable and open up the Universal Reader Assistant.

<figure markdown>
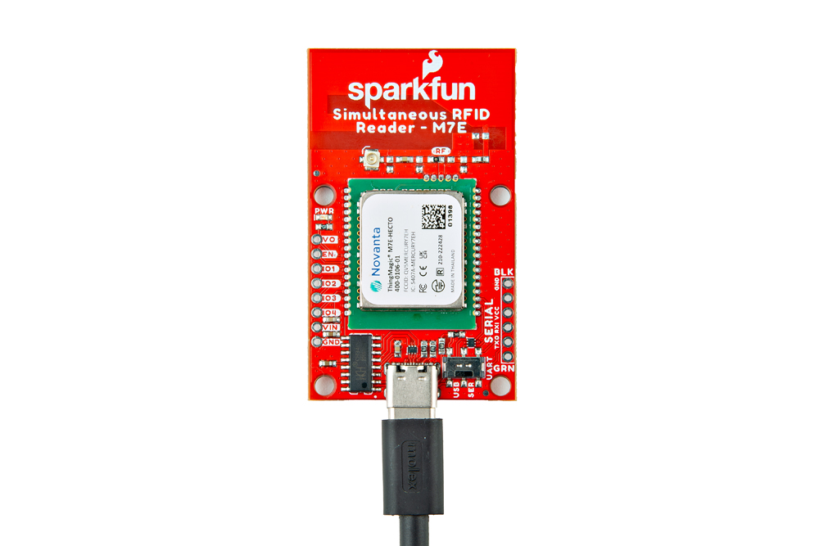
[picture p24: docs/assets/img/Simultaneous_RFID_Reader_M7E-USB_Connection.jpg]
Photo showing basic USB assembly.

</figure>

Reminder, many computer USB ports can only supply <b>~500mA @5V</b> which limits the power level settings to roughly 20dBm and lower. Running the M7E at higher power levels may require a dedicated power supply.

## Communicating via Serial PTH Header

Users who prefer to communicate with the RFID reader using the Serial PTH header should solder either wires or header pins to connect them to a <b>3.3V</b> microcontroller (you can also use this to connect to a USB UART board like the [Serial Basic](https://www.sparkfun.com/products/15096). If you are not familiar with through-hole soldering or would like a refresher, take a read through [this tutorial](https://learn.sparkfun.com/tutorials/how-to-solder-through-hole-soldering).

<figure markdown>
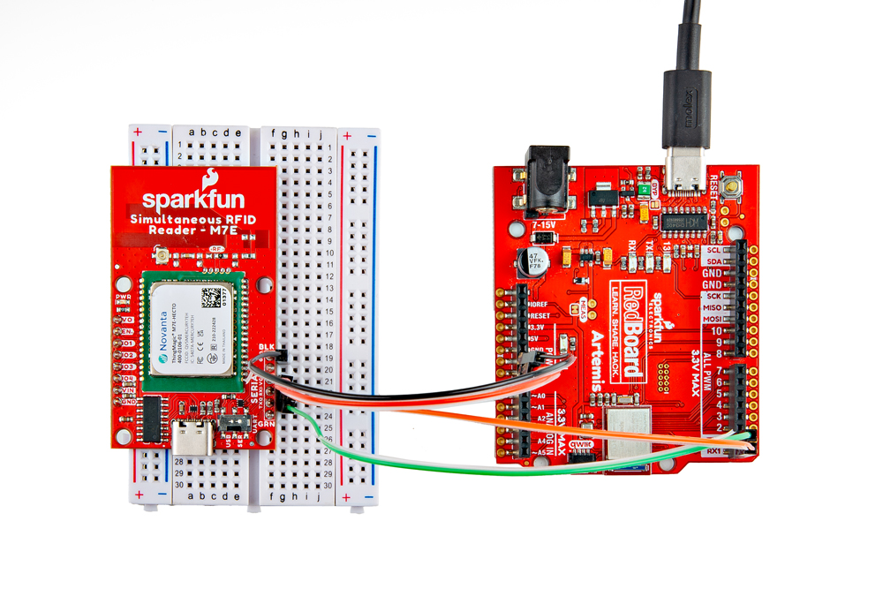
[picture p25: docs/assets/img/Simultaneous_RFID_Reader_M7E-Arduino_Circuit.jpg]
Photo showing Arduino circuit assembly

</figure>

We'll demonstrate soldering male headers to the board and use jumper wires to connect the RFID Reader to the [SparkFun RedBoard Artemis](https://www.sparkfun.com/products/15444) for use with the [SparkFun Simultaneous RFID Tag Reader Arduino Library](https://github.com/sparkfun/SparkFun_Simultaneous_RFID_Tag_Reader_Library).

<table>
    <tr>
        <th>RFID Reader</th>
        <th>RedBoard Artemis</th>
    </tr>
    <tr>
        <td>RX</td>
        <td>TX / D2</sup></td>
    </tr>
    <tr>
        <td>TX</td>
        <td>RX / D3</sup></td>
    </tr>
    <tr>
        <td>VIN</sup></td>
        <td>5V</td>
    </tr>
    <tr>
        <td>Ground</td>
        <td>Ground</td>
    </tr>
</table>

!!! note "Digital Pin Selections"

    Digital pin values are the default selections for Software Serial in the [Simulataneous RFID Reader Arduino Library](https://github.com/sparkfun/SparkFun_Simultaneous_RFID_Tag_Reader_Library) and may be incompatible with your selected microcontroller. Refer to the [Arduino Software Serial Reference](https://docs.arduino.cc/learn/built-in-libraries/software-serial#limitations-of-this-library) for pin limitations for common microcontrollers.

### Power Supply Considerations

When connecting the Simultaneous RFID Reader - M7E to a microcontroller, make sure your power supply can source sufficient current for your selected power level as the board can draw up to <b>720mA @5V</b> at max read power level. The M7E's internal voltage regulator includes built-in protection that engages when the current draw reaches <b>1A</b> and will not allow any more supply current to the module. As such, it is strongly recommended to use a <b>5V</b> power supply when setting the read power to above +26 dBm.

If you opt to power the RFID Reader from your development board's output voltage we recommend using the <b>5V</b> out (if applicable) and then powering your development board through a dedicated power supply to avoid browning the circuit out as USB ports can only source <b>~500mA@5V</b>. The image below shows the Simultaneous RFID Reader - M7E connected to the RedBoard IoT and powered with a dedicated power supply through the barrel jack.

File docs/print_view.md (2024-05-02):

---
hide:
  - navigation
  - toc
icon: fontawesome/solid/scroll
---

# Introduction
--8<-- "./docs/introduction.md:5"

# Hardware Overview
--8<-- "./docs/hardware_overview.md:5"

# Hardware Assembly - Simple Assembly
--8<-- "./docs/hardware_assembly.md:5"

# Hardware Assembly - Using an External Antenna
--8<-- "./docs/external_antenna.md:5"

# Hardware Assembly - Thermal Management Considerations
--8<-- "./docs/thermal_management.md:5"

# Using the ThingMagic Universal Reader Assistant
--8<-- "./docs/universal_assistant.md:5"

# SparkFun Simultaneous RFID Reader Arduino Library - Library Setup
--8<-- "./docs/software_setup.md:5"

# SparkFun Simultaneous RFID Reader Arduino Library - Arduino Examples
--8<-- "./docs/examples.md:5"

# Troubleshooting
--8<-- "./docs/troubleshooting.md"

# Resources
--8<-- "./docs/resources.md"

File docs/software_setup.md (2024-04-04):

---
icon: simple/arduino
---

!!! attention
	If this is your first time using Arduino, please read through our tutorial on [installing the Arduino IDE](https://learn.sparkfun.com/tutorials/installing-arduino-ide). If you have not installed an Arduino library before, we recommend you check out our [installation guide](https://learn.sparkfun.com/tutorials/installing-an-arduino-library).

The SparkFun Simultaneous RFID Tag Reader Arduino library, while originally written for the M6E-NANO, works just as well for the M7E-HECTO on this RFID Reader breakout. The library handles all serial communication, byte manipulations, and CRC verifications making it easy to quickly get started using the board. Users can download and install the library through the Arduino Library Manager by searching for <b>"SparkFun Simultaneous RFID"</b> and selecting the latest version. If you prefer to manually install the library, download a ZIP of it by clicking the button below:

<center>
[SparkFun Simultaneous RFID Tag Reader Arduino Library (ZIP)](https://github.com/sparkfun/SparkFun_Simultaneous_RFID_Tag_Reader_Library/archive/refs/heads/master.zip){ .md-button .md-button--primary }
</center>

With the library installed, let's take a closer look at some of the examples included in it. You can take a look at them by navigating to <b>File > Examples > SparkFun Simultaneous RFID Tag Reader Library > Examples</b>.

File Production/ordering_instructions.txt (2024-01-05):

panel size, 122x208mm
PCB thickness, 1.6mm
number of layers, 2
soldermask color, Red
silkscreen color, White
oz copper, 1oz
finish, HASL lead free
stencils, top
pcs per panel, 9
min trace width, 0.1270mm / 0.0050in
min drill size, 0.3048mm / 0.0120in

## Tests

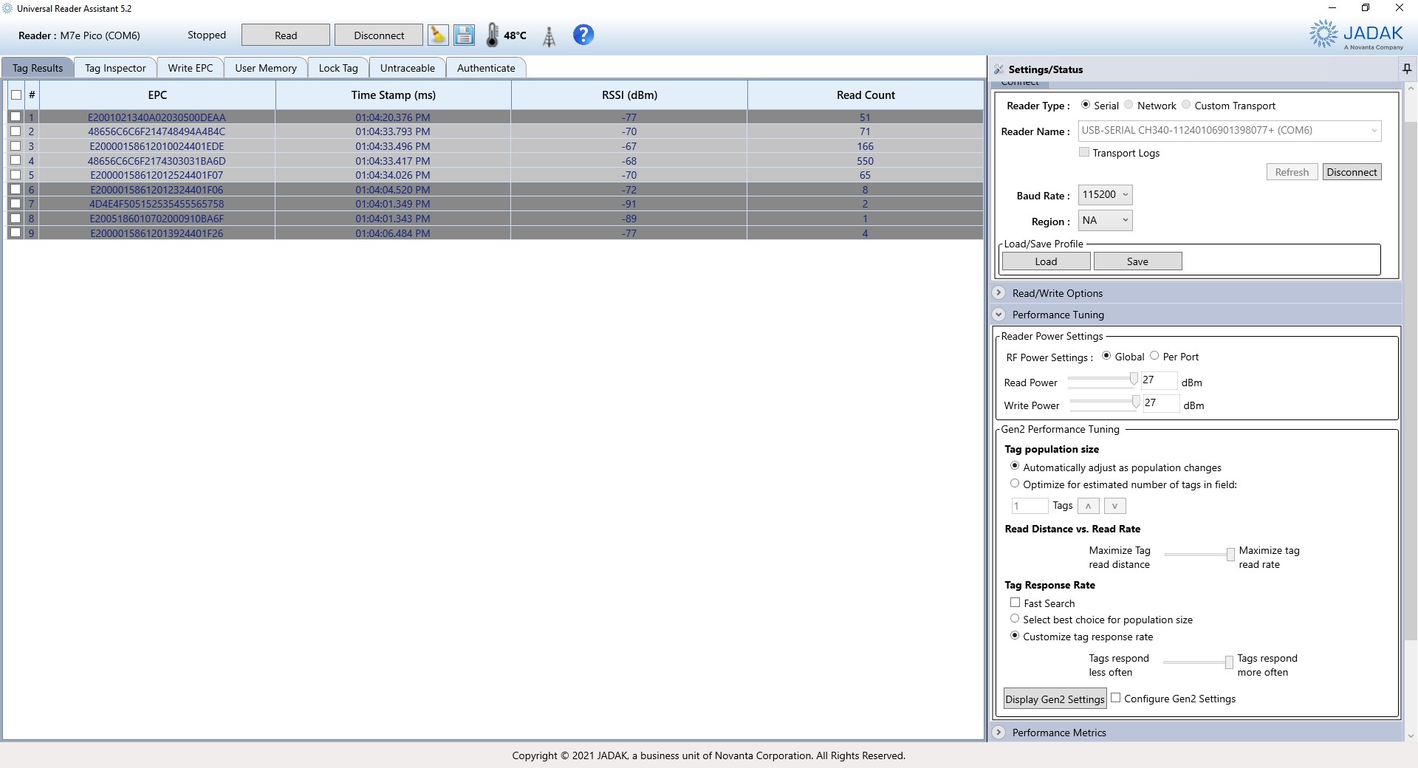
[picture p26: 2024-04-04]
docs/assets/img/URA-Performance_Tuning.jpg

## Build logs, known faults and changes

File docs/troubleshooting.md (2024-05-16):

## Power Supply

Make sure your selected power supply can source enough current to power the Simultaneous RFID Reader - M7E to avoid brown outs as the board can draw over <b>720mA @5V</b> when read power is maxed out. Refer to page 29, "DC Power Requirements" of the [M7E Hecto Design Guide](./assets/component_documentation/M7E_HECTO_User_Guide.pdf) for a detailed chart of current draw at various input voltages and read power levels.

## Thermal Throttling

The M7E has built-in thermal protection that will throttle itself to prevent permanent damage from heat. This board has a thermal pad to help dissipate heat for some applications but if you plan to run the M7E at high read powers for extended periods of time (1hr +), we recommend attaching an external heat sink to the thermal pad.

You can also use the module's ability to change read duty cycle to reduce the heat dissipation as well. Check out the [M7E Hecto Design Guide](./assets/component_documentation/M7E_HECTO_User_Guide.pdf) for more information.

## Logic Levels

Reminder, the Simultaneous RFID Reader M7E 3.3V operates at <b>3.3V</b> logic. Make sure any devices (development board or serial converter) connected to the serial interface operate at <b>3.3V</b> logic or are properly [shifted](https://learn.sparkfun.com/tutorials/logic-levels) to avoid damaging the M7E Hecto.

## Range Discrepancies

The functional range of the Simultaneous RFID Reader - M7E depends on a wide variety of factors and any one of these can increase or decrease the range at which tags are read. Make sure the antenna (either PCB or external) is free of anything that may cause interference. For example, the PCB antenna's range can drastically change depending on whether it is in open space or next to a solid object (such as a desk or person). Similarly, a tag's position in relation to the antenna as well as any solid objects (again, think person or other object) it may be near or placed on can significantly change the range.

For ideal range, make sure both the antenna and tag are in as much open space as possible and positioned in line with the antenna's radiation pattern. 

## General Troubleshooting and Technical Assistance

If you need technical assistance and more information on a product that is not working as you expected, we recommend heading on over to the [SparkFun Technical Assistance](https://www.sparkfun.com/technical_assistance) page for some initial troubleshooting.

<center>
[SparkFun Technical Assistance Page](https://www.sparkfun.com/technical_assistance){ .md-button .md-button--primary }
</center>

If you don't find what you need there, the [SparkFun Forums](https://forum.sparkfun.com/index.php) are a great place to find and ask for help. If this is your first visit, you'll need to [create a Forum Account](https://forum.sparkfun.com/ucp.php?mode=register) to search product forums and post questions.<br /><br />

<center>
[Create New Forum Account](https://forum.sparkfun.com/ucp.php?mode=register){ .md-button .md-button--primary }
</center>

<center>
[Log Into SparkFun Forums](https://forum.sparkfun.com/index.php){ .md-button .md-button--primary }
</center>

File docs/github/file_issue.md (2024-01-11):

# Did we make a mistake?

Spot something wrong? Please let us know. 

<!-- Technical Assistance Box -->
!!! warning "Need Help?"
    If you need technical assistance or more information on a product that is not working as you expected, we recommend heading on over to the [SparkFun Technical Assistance](https://www.sparkfun.com/technical_assistanc) page for some initial troubleshooting. This **Submit Issues** page is not where users should seek assistance.

    <center>
    [SparkFun Technical Assistance Page](https://www.sparkfun.com/technical_assistance){ .md-button .md-button--primary }
    </center>
    
    If you can't find what you need there, the [SparkFun Forums](https://forum.sparkfun.com/index.php) is a great place to search the product forums and ask questions.
    
    !!! info "Account Registration Required"
        For your first visit to our forum, you'll need to create a [Forum Account](https://forum.sparkfun.com/ucp.php?mode=register) to post questions.

## Discrepancies in the Documentation

All of our documentation can be modified by you! Please help us make it better.

* The documentation files for these pages are contained in the [`docs` folder](https://github.com/sparkfun/SparkFun_Simultaneous_RFID_Reader_M7E/tree/main/docs) of the [SparkFun Simultaneous RFID Reader - M7E repository](https://github.com/sparkfun/SparkFun_Simultaneous_RFID_Reader_M7E).

### 🔍 Spot something wrong?

If a section of the documentation is incorrect, please [open an issue](https://github.com/sparkfun/SparkFun_Simultaneous_RFID_Reader_M7E/issues) and let us know.

### Do you have a suggested correction?

1. With a GitHub account, [fork this repository](https://github.com/sparkfun/SparkFun_Simultaneous_RFID_Reader_M7E/fork).
2. Add your correction(s) or improvement(s) to the markdown file(s)
3. File a pull request with your changes, and enjoy making the ~~words~~ ~~worlds~~ world a better place.
	* Once received, the documentation specialist will automatically be notified.
	* We will review your suggested improvement(s) to make sure they are correct and fit within our documentation standards.

## Problems in the Hardware Design

All of our designs are open-source! Please help us make it better.

* Our board design files are contained in the [`Hardware` folder](https://github.com/sparkfun/SparkFun_Simultaneous_RFID_Reader_M7E/tree/main/Hardware) of the [SparkFun Simultaneous RFID Reader - M7E repository](https://github.com/sparkfun/SparkFun_Simultaneous_RFID_Reader_M7E).

### Does something not make sense? 🤔

If part of the design is confusing, please [open an issue](https://github.com/sparkfun/SparkFun_Simultaneous_RFID_Reader_M7E/issues) and let us know.

### Did we forget to include an important function of the board? 🤦

If part of the board's functionality is missing, please [open an issue](https://github.com/sparkfun/SparkFun_Simultaneous_RFID_Reader_M7E/issues) and file a feature request.

!!! tip "Design Considerations"
	Please keep in mind that we may intentionally exclude certain functions of the board to meet our product design requirements.
	
	* *For example, our Qwiic Micro boards are intended to fit on a small board layout and only use I<sup>2</sup>C communication; therefore, we may not have the SPI and interrupt pins available for users.*

### Do you wish to contribute directly to improving the board design?

1. With a GitHub account, [fork this repository](https://github.com/sparkfun/SparkFun_Simultaneous_RFID_Reader_M7E/fork).
2. Add your design augmentation(s)
3. File a pull request with your changes, and enjoy making the ~~words~~ ~~worlds~~ world a better place.
	1. Once received, the engineer in charge of the original design will automatically be notified.
	2. We will review your suggested improvement(s) to verify that they are within our board design standards and meet our product design requirements.
	3. If approved, we will flag these changes for our next board revision. Congrats! 🍻

		!!! info
			Even if your suggestion is accepted, these changes may not be immediately available for purchase. We may have to cycle through our current product inventory first.

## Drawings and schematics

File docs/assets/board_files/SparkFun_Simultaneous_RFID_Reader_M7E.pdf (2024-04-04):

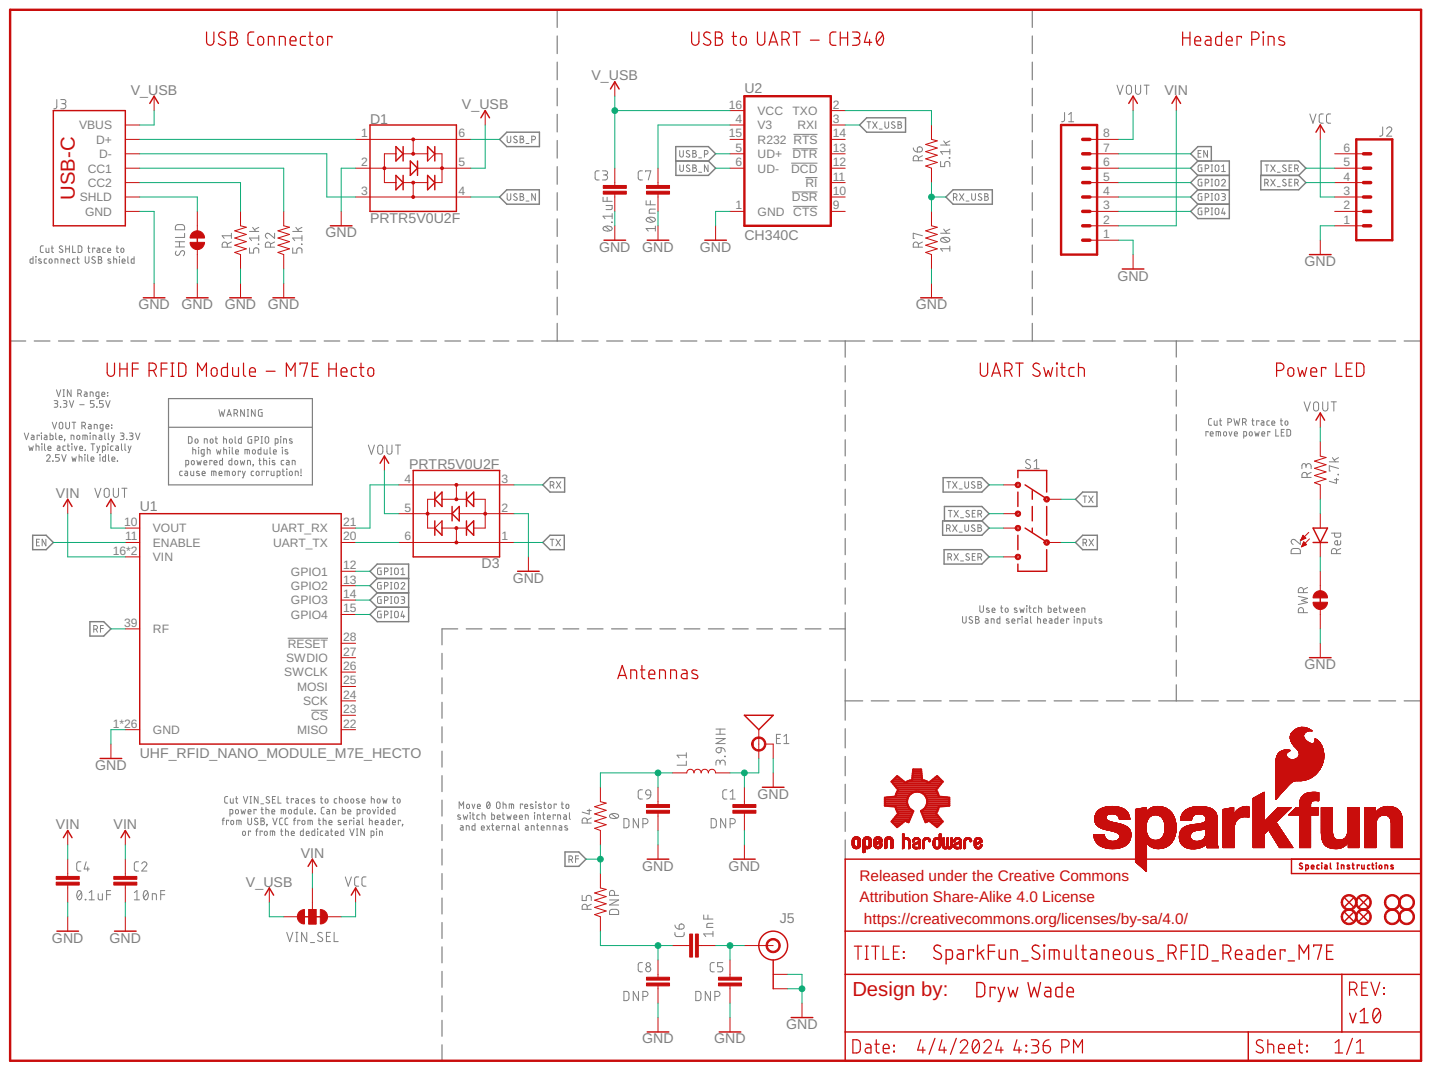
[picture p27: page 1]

Released under the Creative Commons Attribution Share-Alike 4.0 License

https://creativecommons.org/licenses/by-sa/4.0/

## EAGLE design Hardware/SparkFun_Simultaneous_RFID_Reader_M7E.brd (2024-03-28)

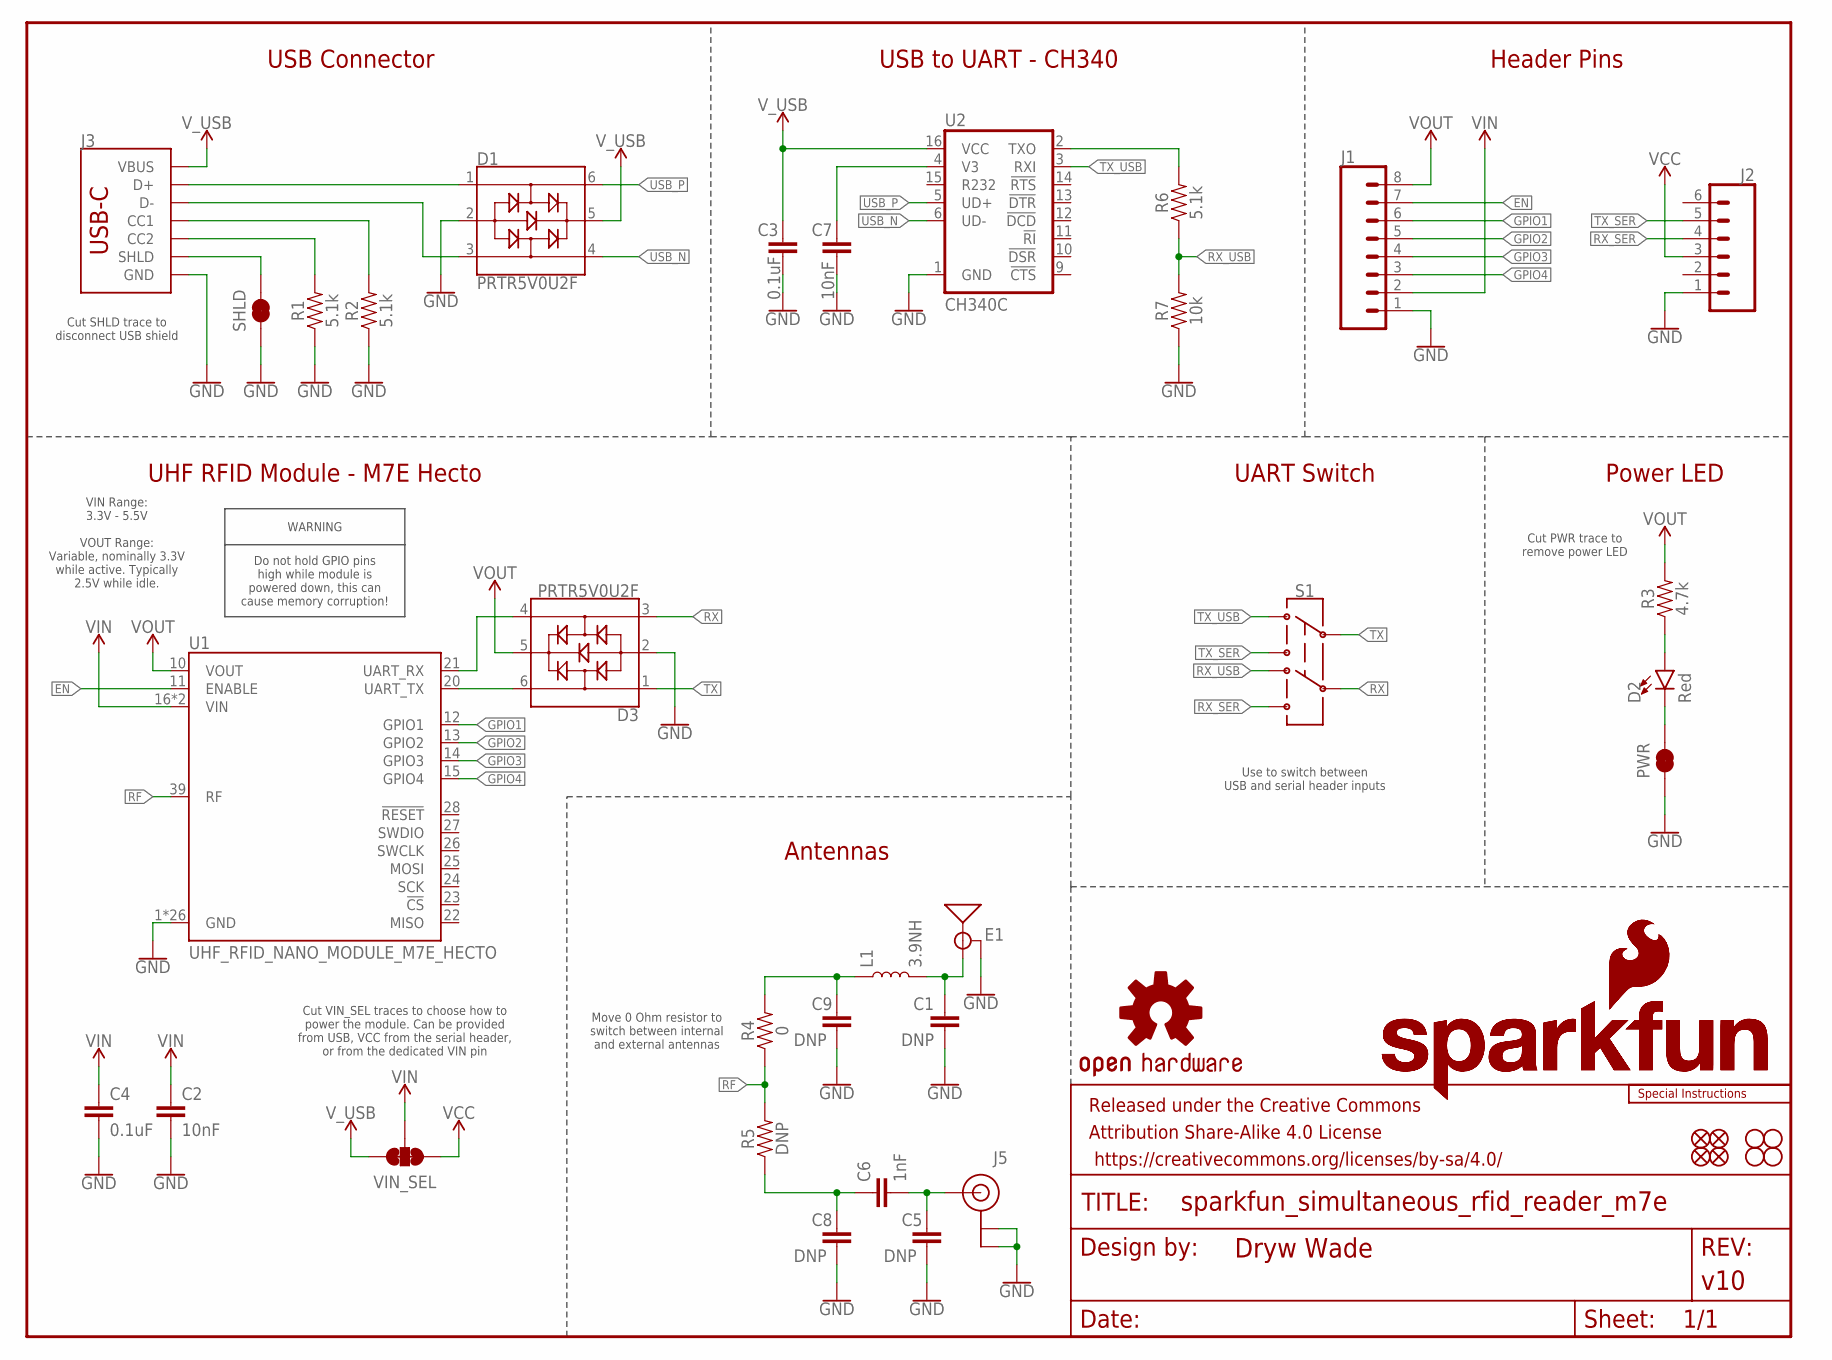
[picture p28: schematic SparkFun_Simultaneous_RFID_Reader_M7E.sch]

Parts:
C1, C5, C8, C9: DNP; 0603
C2, C7: 10nF; 0603
C3, C4: 0.1uF; 0603
C6: 1nF; 0603
D1, D3: PRTR5V0U2F; SOT886
D2: Red; LED-0603
E1: ANTENNA-GROUNDEDTRACE-915MHZ; TRACE_ANTENNA_915MHZ_THINGMAGIC
FD1, FD2, FD3, FD4: FIDUCIAL1X2; FIDUCIAL-1X2
FRAME1: FRAME-LETTER; CREATIVE_COMMONS
H1, H2, H3, H4: STAND-OFF
J1: CONN_08NO_SILK_DNP; 1X08_NO_SILK
J2: CONN_06NO_SILK_NO_POP; 1X06_NO_SILK
J3: USB_C_2-LAYER_PADS; USB-C-16P-2LAYER-PADS
J5: U.FL
L1: 3.9NH; 0603
LOGO1: OSHW-LOGOM; OSHW-LOGO-M
LOGO2, LOGO3: SFE_LOGO_NAME_FLAME.2_INCH; SFE_LOGO_NAME_FLAME_.2
LOGO4: SPECIAL_INSTRUCTIONS-ORDERING; ORDERING_INSTRUCTIONS
PWR: JUMPER-SMT_2_NC_TRACE_SILK; SMT-JUMPER_2_NC_TRACE_SILK
R1, R2, R6: 5.1k; 0603
R3: 4.7k; 0603
R4: 0; 0603
R5: DNP; 0603
R7: 10k; 0603
S1: SWITCH-DPDT-SMD-AYZ0202; SWITCH_DPDT_SMD_AYZ0202
SHLD: JUMPER-SMT_2_NC_TRACE_SILK; SMT-JUMPER_2_NC_TRACE_SILK
U1: UHF_RFID_NANO_MODULE_M7E_HECTO; M7E_HECTO_MODULE
U2: CH340C; SO016
VIN_SEL: JUMPER-SMT_3_2-NC_TRACE_SILK; SMT-JUMPER_3_2-NC_TRACE_SILK

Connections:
EN: J1.7, U1.11 (ENABLE)
GND: C1.2, C2.2, C3.2, C4.2, C5.2, C7.2, C8.2, C9.2, D1.2, D3.2, E1.GND@1 (GND), E1.GND@2 (GND), E1.GND@3 (GND), J1.1, J2.1, J3.GND, J3.GND2 (GND), J5.1 (GND), J5.2 (GND), PWR.1, R1.1, R2.1, R7.1, SHLD.1, U1.1 (GND), U1.2 (GND), U1.3 (GND), U1.4 (GND), U1.5 (GND), U1.6 (GND), U1.7 (GND), U1.8 (GND), U1.9 (GND), U1.18 (GND), U1.19 (GND), U1.29 (GND), U1.30 (GND), U1.31 (GND), U1.32 (GND), U1.33 (GND), U1.34 (GND), U1.35 (GND), U1.36 (GND), U1.37 (GND), U1.38 (GND), U1.40 (GND), U1.41 (GND), U1.GND_PAD1 (GND), U1.GND_PAD2 (GND), U1.GND_PAD3 (GND), U2.1 (GND)
GPIO1: J1.6, U1.12 (GPIO1)
GPIO2: J1.5, U1.13 (GPIO2)
GPIO3: J1.4, U1.14 (GPIO3)
GPIO4: J1.3, U1.15 (GPIO4)
unnamed: C1.1, E1.ANT (SIGNAL), L1.2
unnamed: D2.A, R3.1
unnamed: J3.B5 (CC2), R1.2
unnamed: J3.A5 (CC1), R2.2
unnamed: D1.1, J3.A6 (D+), J3.B6 (D+)
unnamed: D2.C, PWR.2
unnamed: D1.3, J3.A7 (D-), J3.B7 (D-)
unnamed: C6.1, C8.1, R5.1
unnamed: C5.1, C6.2, J5.FEED (SIGNAL)
unnamed: C9.1, L1.1, R4.2
unnamed: C7.1, U2.4 (V3)
unnamed: D3.6, U1.20 (UART_TX)
unnamed: D3.4, U1.21 (UART_RX)
unnamed: R6.2, U2.2 (TXO)
RF: R4.1, R5.2, U1.39 (RF)
RX: D3.3, S1.5
RX_SER: J2.4, S1.4
RX_USB: R6.1, R7.2, S1.6
SHLD: J3.SHLD1 (SHLD), J3.SHLD2 (SHLD), J3.SHLD3 (SHLD), J3.SHLD4 (SHLD), SHLD.2
TX: D3.1, S1.2
TX_SER: J2.5, S1.1
TX_USB: S1.3, U2.3 (RXI)
USB_N: D1.4, U2.6 (UD-)
USB_P: D1.6, U2.5 (UD+)
VCC: J2.3, VIN_SEL.1
VIN: C2.1, C4.1, J1.2, U1.16 (VIN), U1.17 (VIN), VIN_SEL.2
VOUT: D3.5, J1.8, R3.2, U1.10 (VOUT)
V_USB: C3.1, D1.5, J3.VBUS1 (VBUS), J3.VBUS2 (VBUS), U2.16 (VCC), VIN_SEL.3

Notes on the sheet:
WARNING
Do not hold GPIO pins high while module is powered down, this can cause memory corruption!
Cut VIN_SEL traces to choose how to power the module. Can be provided from USB, VCC from the serial header, or from the dedicated VIN pin
Cut SHLD trace to disconnect USB shield
USB Connector
USB to UART - CH340
Header Pins
Power LED
Antennas
UHF RFID Module - M7E Hecto
UART Switch
Move 0 Ohm resistor to switch between internal and external antennas
VOUT Range: Variable, nominally 3.3V while active. Typically 2.5V while idle.
Cut PWR trace to remove power LED
Use to switch between USB and serial header inputs
VIN Range: 3.3V - 5.5V

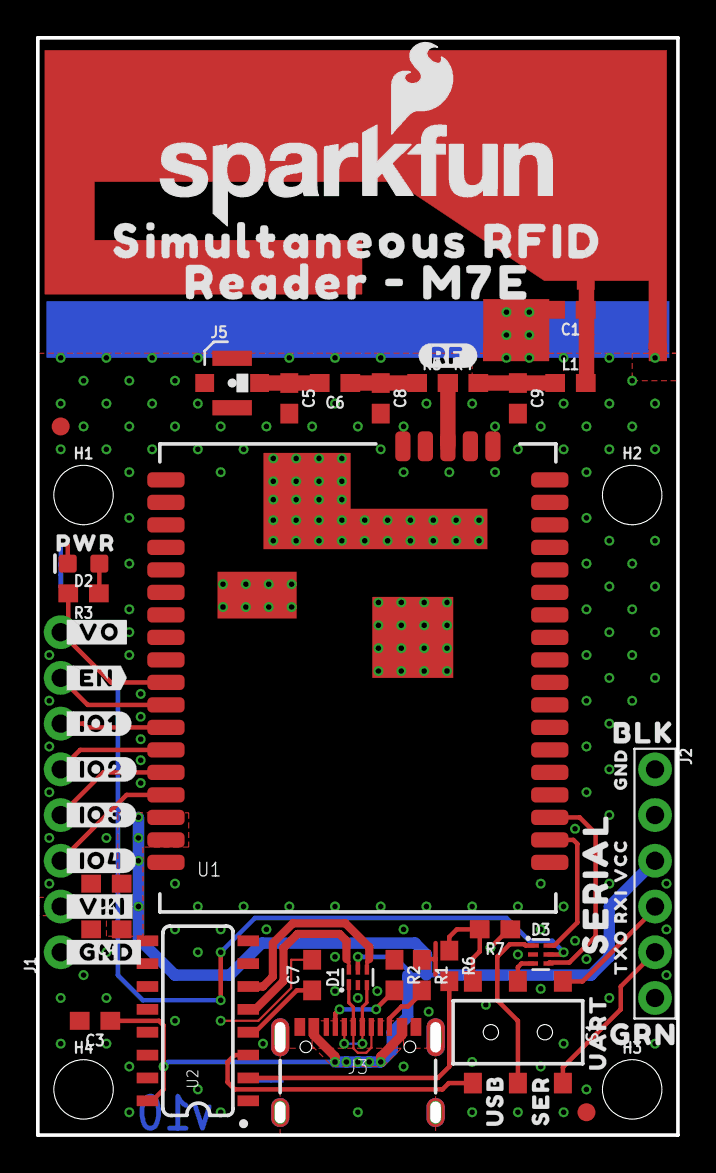
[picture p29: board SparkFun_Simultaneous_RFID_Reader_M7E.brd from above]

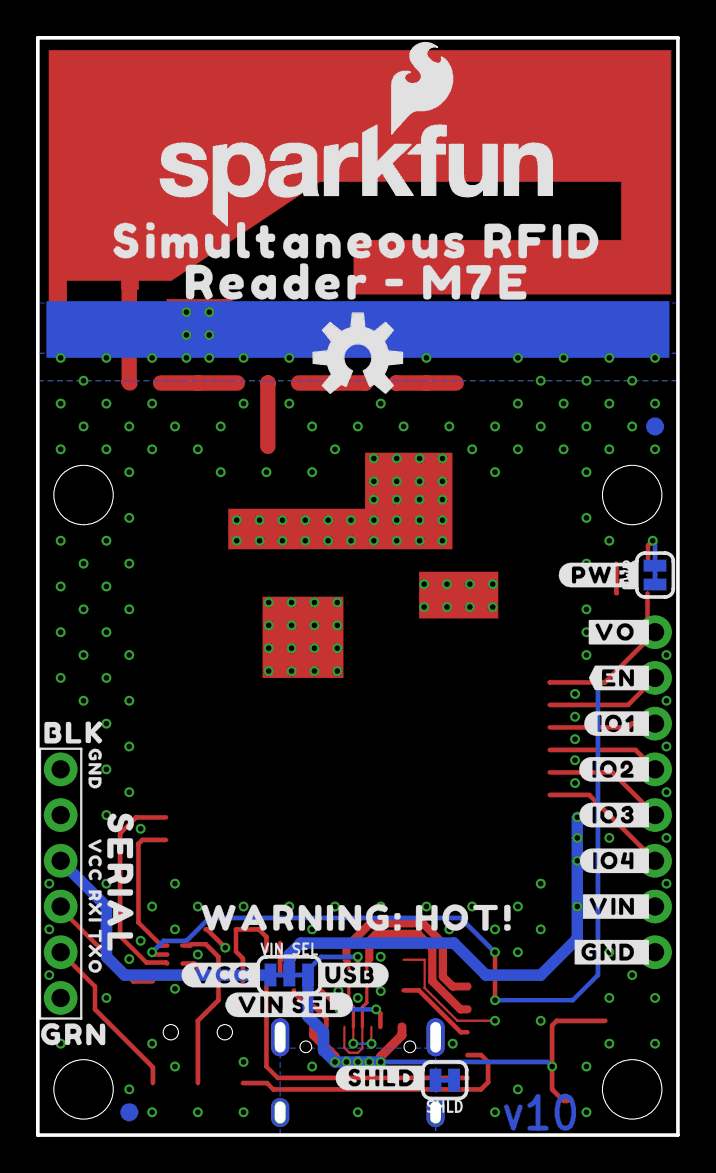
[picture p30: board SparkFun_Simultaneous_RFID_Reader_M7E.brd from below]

Board: 2 copper layers, 35.6 x 61.0 mm, 77 parts (24 on the bottom side), 34 nets.

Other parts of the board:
U$1, U$19: SIMULTANEOUS_RFID0
U$2, U$20: READER_#_M7E0
U$3: #USB#0
U$4: #VCC#0
U$5, U$7: SERIAL0
U$6: #_GND#0
U$8: UART0
U$10: #_VIN#0
U$11: #_IO4#0
U$12: #_IO3#0
U$13: #_IO2#0
U$14: #_IO1#0
U$15: #_EN#0
U$16: SER0
U$17: #VIN_SEL#0
U$18: #VO_#0
U$21: #_VO#0
U$27: #GND_#0
U$39: #EN_#0
U$40: #IO1_#0
U$41: #IO2_#0
U$42: #IO3_#0
U$43: #IO4_#0
U$44: #VIN_#0
U$45: USB0
U$49: #PWR#0
U$50: #SHLD#0
U$52: PWR0
U$56: #RF#0
U$57: WARNING#_HOT##0

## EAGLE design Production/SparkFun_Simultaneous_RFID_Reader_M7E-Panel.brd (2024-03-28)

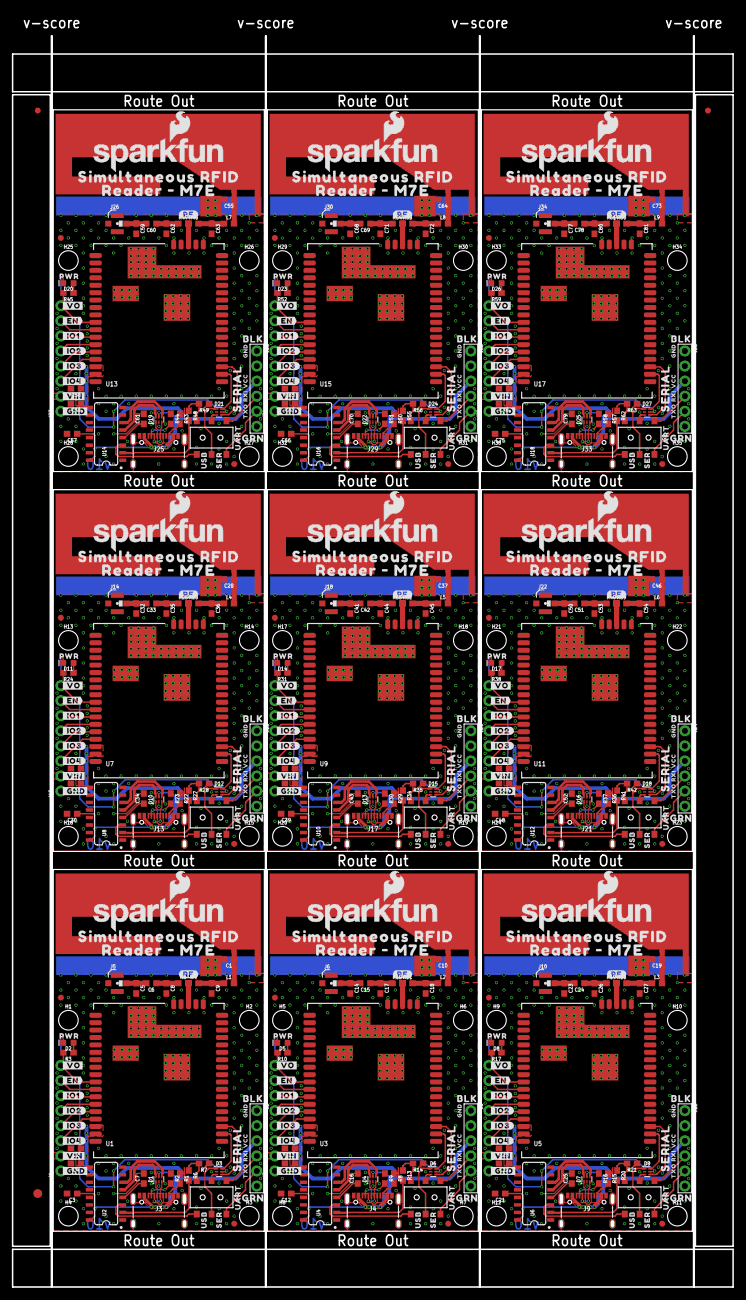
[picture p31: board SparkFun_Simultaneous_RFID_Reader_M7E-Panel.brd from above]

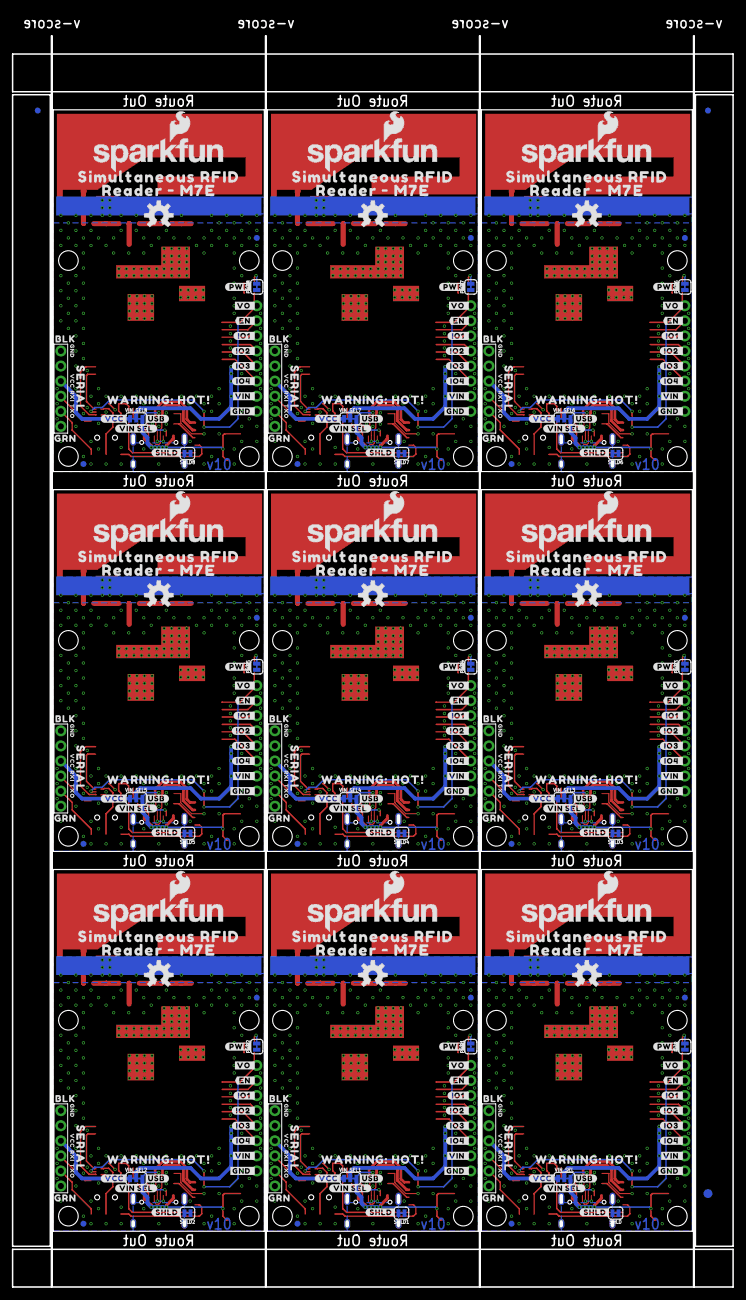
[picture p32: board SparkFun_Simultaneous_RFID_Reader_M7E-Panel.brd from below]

Board: 2 copper layers, 121.4 x 210.8 mm, 681 parts (219 on the bottom side), 306 nets.

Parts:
C1, C5, C8, C9, C10, C14, C17, C18, C19, C23, C26, C27, C28, C32, C35, C36, C37, C41, C44, C45, C46, C50, C53, C54, C55, C59, C62, C63, C64, C68, C71, C72, C73, C77, C80, C81: DNP; 0603
C2, C7, C11, C16, C20, C25, C29, C34, C38, C43, C47, C52, C56, C61, C65, C70, C74, C79: 10nF; 0603
C3, C4, C12, C13, C21, C22, C30, C31, C39, C40, C48, C49, C57, C58, C66, C67, C75, C76: 0.1uF; 0603
C6, C15, C24, C33, C42, C51, C60, C69, C78: 1nF; 0603
D1, D3, D4, D6, D7, D9, D10, D12, D13, D15, D16, D18, D19, D21, D22, D24, D25, D27: PRTR5V0U2F; SOT886
D2, D5, D8, D11, D14, D17, D20, D23, D26: Red; LED-0603
E1, E2, E3, E4, E5, E6, E7, E8, E9: ANTENNA-GROUNDEDTRACE-915MHZ; TRACE_ANTENNA_915MHZ_THINGMAGIC
E$1, E$2, E$3, E$4: FIDUCIAL-1X2
E$5, E$6: FIDUCIAL-1.5X3
FD1, FD2, FD3, FD4, FD5, FD6, FD7, FD8, FD9, FD10, FD11, FD12, FD13, FD14, FD15, FD16, FD17, FD18, FD19, FD20, FD21, FD22, FD23, FD24, FD25, FD26, FD27, FD28, FD29, FD30, FD31, FD32, FD33, FD34, FD35, FD36: FIDUCIAL1X2; FIDUCIAL-1X2
H1, H2, H3, H4, H5, H6, H7, H8, H9, H10, H11, H12, H13, H14, H15, H16, H17, H18, H19, H20, H21, H22, H23, H24, H25, H26, H27, H28, H29, H30, H31, H32, H33, H34, H35, H36: STAND-OFF
J1, J7, J11, J15, J19, J23, J27, J31, J35: 1X08_NO_SILK
J2, J8, J12, J16, J20, J24, J28, J32, J36: 1X06_NO_SILK
J3, J4, J9, J13, J17, J21, J25, J29, J33: USB-C-16P-2LAYER-PADS
J5, J6, J10, J14, J18, J22, J26, J30, J34: U.FL
L1, L2, L3, L4, L5, L6, L7, L8, L9: 3.9NH; 0603
LOGO1, LOGO4, LOGO7, LOGO10, LOGO13, LOGO16, LOGO19, LOGO22, LOGO25: OSHW-LOGOM; OSHW-LOGO-M
LOGO2, LOGO3, LOGO5, LOGO6, LOGO8, LOGO9, LOGO11, LOGO12, LOGO14, LOGO15, LOGO17, LOGO18, LOGO20, LOGO21, LOGO23, LOGO24, LOGO26, LOGO27: SFE_LOGO_NAME_FLAME.2_INCH; SFE_LOGO_NAME_FLAME_.2
PWR, PWR1, PWR2, PWR3, PWR4, PWR5, PWR6, PWR7, PWR8: JUMPER-SMT_2_NC_TRACE_SILK; SMT-JUMPER_2_NC_TRACE_SILK
R1, R2, R6, R8, R9, R13, R15, R16, R20, R22, R23, R27, R29, R30, R34, R36, R37, R41, R43, R44, R48, R50, R51, R55, R57, R58, R62: 5.1k; 0603
R3, R10, R17, R24, R31, R38, R45, R52, R59: 4.7k; 0603
R4, R11, R18, R25, R32, R39, R46, R53, R60: 0; 0603
R5, R12, R19, R26, R33, R40, R47, R54, R61: DNP; 0603
R7, R14, R21, R28, R35, R42, R49, R56, R63: 10k; 0603
S1, S2, S3, S4, S5, S6, S7, S8, S9: SWITCH_DPDT_SMD_AYZ0202
SHLD, SHLD1, SHLD2, SHLD3, SHLD4, SHLD5, SHLD6, SHLD7, SHLD8: JUMPER-SMT_2_NC_TRACE_SILK; SMT-JUMPER_2_NC_TRACE_SILK
U1, U3, U5, U7, U9, U11, U13, U15, U17: UHF_RFID_NANO_MODULE_M7E_HECTO; M7E_HECTO_MODULE
U2, U4, U6, U8, U10, U12, U14, U16, U18: CH340C; SO016
U$1, U$19, U$58, U$60, U$91, U$93, U$124, U$126, U$157, U$159, U$190, U$192, U$223, U$225, U$256, U$258, U$289, U$291: SIMULTANEOUS_RFID0
U$2, U$20, U$59, U$61, U$92, U$94, U$125, U$127, U$158, U$160, U$191, U$193, U$224, U$226, U$257, U$259, U$290, U$292: READER_#_M7E0
U$3, U$62, U$95, U$128, U$161, U$194, U$227, U$260, U$293: #USB#0
U$4, U$63, U$96, U$129, U$162, U$195, U$228, U$261, U$294: #VCC#0
U$5, U$7, U$51, U$53, U$87, U$88, U$120, U$121, U$153, U$154, U$186, U$187, U$219, U$220, U$252, U$253, U$285, U$286: SERIAL0
U$6, U$9, U$67, U$100, U$133, U$166, U$199, U$232, U$265: #_GND#0
U$8, U$54, U$89, U$122, U$155, U$188, U$221, U$254, U$287: UART0
U$10, U$22, U$68, U$101, U$134, U$167, U$200, U$233, U$266: #_VIN#0
U$11, U$23, U$69, U$102, U$135, U$168, U$201, U$234, U$267: #_IO4#0
U$12, U$24, U$70, U$103, U$136, U$169, U$202, U$235, U$268: #_IO3#0
U$13, U$25, U$71, U$104, U$137, U$170, U$203, U$236, U$269: #_IO2#0
U$14, U$26, U$72, U$105, U$138, U$171, U$204, U$237, U$270: #_IO1#0
U$15, U$28, U$73, U$106, U$139, U$172, U$205, U$238, U$271: #_EN#0
U$16, U$55, U$90, U$123, U$156, U$189, U$222, U$255, U$288: SER0
U$17, U$64, U$97, U$130, U$163, U$196, U$229, U$262, U$295: #VIN_SEL#0
U$18, U$66, U$99, U$132, U$165, U$198, U$231, U$264, U$297: #VO_#0
U$21, U$65, U$98, U$131, U$164, U$197, U$230, U$263, U$296: #_VO#0
U$27, U$29, U$74, U$107, U$140, U$173, U$206, U$239, U$272: #GND_#0
U$30, U$39, U$75, U$108, U$141, U$174, U$207, U$240, U$273: #EN_#0
U$31, U$40, U$76, U$109, U$142, U$175, U$208, U$241, U$274: #IO1_#0
U$32, U$41, U$77, U$110, U$143, U$176, U$209, U$242, U$275: #IO2_#0
U$33, U$42, U$78, U$111, U$144, U$177, U$210, U$243, U$276: #IO3_#0
U$34, U$43, U$79, U$112, U$145, U$178, U$211, U$244, U$277: #IO4_#0
U$35, U$44, U$80, U$113, U$146, U$179, U$212, U$245, U$278: #VIN_#0
U$36, U$45, U$81, U$114, U$147, U$180, U$213, U$246, U$279: USB0
U$37, U$49, U$82, U$115, U$148, U$181, U$214, U$247, U$280: #PWR#0
U$38, U$50, U$83, U$116, U$149, U$182, U$215, U$248, U$281: #SHLD#0
U$46, U$52, U$84, U$117, U$150, U$183, U$216, U$249, U$282: PWR0
U$47, U$56, U$85, U$118, U$151, U$184, U$217, U$250, U$283: #RF#0
U$48, U$57, U$86, U$119, U$152, U$185, U$218, U$251, U$284: WARNING#_HOT##0
VIN_SEL, VIN_SEL1, VIN_SEL2, VIN_SEL3, VIN_SEL4, VIN_SEL5, VIN_SEL6, VIN_SEL7, VIN_SEL8: JUMPER-SMT_3_2-NC_TRACE_SILK; SMT-JUMPER_3_2-NC_TRACE_SILK

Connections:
EN: J1.7, U1.11
EN1: J7.7, U3.11
EN2: J11.7, U5.11
EN3: J15.7, U7.11
EN4: J19.7, U9.11
EN5: J23.7, U11.11
EN6: J27.7, U13.11
EN7: J31.7, U15.11
EN8: J35.7, U17.11
GND: C1.2, C2.2, C3.2, C4.2, C5.2, C7.2, C8.2, C9.2, D1.2, D3.2, E1.GND@1, E1.GND@2, E1.GND@3, J1.1, J2.1, J3.GND, J3.GND2, J5.1, J5.2, PWR.1, R1.1, R2.1, R7.1, SHLD.1, U1.1, U1.2, U1.3, U1.4, U1.5, U1.6, U1.7, U1.8, U1.9, U1.18, U1.19, U1.29, U1.30, U1.31, U1.32, U1.33, U1.34, U1.35, U1.36, U1.37, U1.38, U1.40, U1.41, U1.GND_PAD1, U1.GND_PAD2, U1.GND_PAD3, U2.1
GND1: C10.2, C11.2, C12.2, C13.2, C14.2, C16.2, C17.2, C18.2, D4.2, D6.2, E2.GND@1, E2.GND@2, E2.GND@3, J4.GND, J4.GND2, J6.1, J6.2, J7.1, J8.1, PWR1.1, R8.1, R9.1, R14.1, SHLD1.1, U3.1, U3.2, U3.3, U3.4, U3.5, U3.6, U3.7, U3.8, U3.9, U3.18, U3.19, U3.29, U3.30, U3.31, U3.32, U3.33, U3.34, U3.35, U3.36, U3.37, U3.38, U3.40, U3.41, U3.GND_PAD1, U3.GND_PAD2, U3.GND_PAD3, U4.1
GND2: C19.2, C20.2, C21.2, C22.2, C23.2, C25.2, C26.2, C27.2, D7.2, D9.2, E3.GND@1, E3.GND@2, E3.GND@3, J9.GND, J9.GND2, J10.1, J10.2, J11.1, J12.1, PWR2.1, R15.1, R16.1, R21.1, SHLD2.1, U5.1, U5.2, U5.3, U5.4, U5.5, U5.6, U5.7, U5.8, U5.9, U5.18, U5.19, U5.29, U5.30, U5.31, U5.32, U5.33, U5.34, U5.35, U5.36, U5.37, U5.38, U5.40, U5.41, U5.GND_PAD1, U5.GND_PAD2, U5.GND_PAD3, U6.1
GND3: C28.2, C29.2, C30.2, C31.2, C32.2, C34.2, C35.2, C36.2, D10.2, D12.2, E4.GND@1, E4.GND@2, E4.GND@3, J13.GND, J13.GND2, J14.1, J14.2, J15.1, J16.1, PWR3.1, R22.1, R23.1, R28.1, SHLD3.1, U7.1, U7.2, U7.3, U7.4, U7.5, U7.6, U7.7, U7.8, U7.9, U7.18, U7.19, U7.29, U7.30, U7.31, U7.32, U7.33, U7.34, U7.35, U7.36, U7.37, U7.38, U7.40, U7.41, U7.GND_PAD1, U7.GND_PAD2, U7.GND_PAD3, U8.1
GND4: C37.2, C38.2, C39.2, C40.2, C41.2, C43.2, C44.2, C45.2, D13.2, D15.2, E5.GND@1, E5.GND@2, E5.GND@3, J17.GND, J17.GND2, J18.1, J18.2, J19.1, J20.1, PWR4.1, R29.1, R30.1, R35.1, SHLD4.1, U9.1, U9.2, U9.3, U9.4, U9.5, U9.6, U9.7, U9.8, U9.9, U9.18, U9.19, U9.29, U9.30, U9.31, U9.32, U9.33, U9.34, U9.35, U9.36, U9.37, U9.38, U9.40, U9.41, U9.GND_PAD1, U9.GND_PAD2, U9.GND_PAD3, U10.1
GND5: C46.2, C47.2, C48.2, C49.2, C50.2, C52.2, C53.2, C54.2, D16.2, D18.2, E6.GND@1, E6.GND@2, E6.GND@3, J21.GND, J21.GND2, J22.1, J22.2, J23.1, J24.1, PWR5.1, R36.1, R37.1, R42.1, SHLD5.1, U11.1, U11.2, U11.3, U11.4, U11.5, U11.6, U11.7, U11.8, U11.9, U11.18, U11.19, U11.29, U11.30, U11.31, U11.32, U11.33, U11.34, U11.35, U11.36, U11.37, U11.38, U11.40, U11.41, U11.GND_PAD1, U11.GND_PAD2, U11.GND_PAD3, U12.1
GND6: C55.2, C56.2, C57.2, C58.2, C59.2, C61.2, C62.2, C63.2, D19.2, D21.2, E7.GND@1, E7.GND@2, E7.GND@3, J25.GND, J25.GND2, J26.1, J26.2, J27.1, J28.1, PWR6.1, R43.1, R44.1, R49.1, SHLD6.1, U13.1, U13.2, U13.3, U13.4, U13.5, U13.6, U13.7, U13.8, U13.9, U13.18, U13.19, U13.29, U13.30, U13.31, U13.32, U13.33, U13.34, U13.35, U13.36, U13.37, U13.38, U13.40, U13.41, U13.GND_PAD1, U13.GND_PAD2, U13.GND_PAD3, U14.1
GND7: C64.2, C65.2, C66.2, C67.2, C68.2, C70.2, C71.2, C72.2, D22.2, D24.2, E8.GND@1, E8.GND@2, E8.GND@3, J29.GND, J29.GND2, J30.1, J30.2, J31.1, J32.1, PWR7.1, R50.1, R51.1, R56.1, SHLD7.1, U15.1, U15.2, U15.3, U15.4, U15.5, U15.6, U15.7, U15.8, U15.9, U15.18, U15.19, U15.29, U15.30, U15.31, U15.32, U15.33, U15.34, U15.35, U15.36, U15.37, U15.38, U15.40, U15.41, U15.GND_PAD1, U15.GND_PAD2, U15.GND_PAD3, U16.1
GND8: C73.2, C74.2, C75.2, C76.2, C77.2, C79.2, C80.2, C81.2, D25.2, D27.2, E9.GND@1, E9.GND@2, E9.GND@3, J33.GND, J33.GND2, J34.1, J34.2, J35.1, J36.1, PWR8.1, R57.1, R58.1, R63.1, SHLD8.1, U17.1, U17.2, U17.3, U17.4, U17.5, U17.6, U17.7, U17.8, U17.9, U17.18, U17.19, U17.29, U17.30, U17.31, U17.32, U17.33, U17.34, U17.35, U17.36, U17.37, U17.38, U17.40, U17.41, U17.GND_PAD1, U17.GND_PAD2, U17.GND_PAD3, U18.1
GPIO1: J1.6, U1.12
GPIO2: J1.5, U1.13
GPIO3: J1.4, U1.14
GPIO4: J1.3, U1.15
GPIO5: J7.6, U3.12
GPIO6: J7.5, U3.13
GPIO7: J7.4, U3.14
GPIO8: J7.3, U3.15
GPIO9: J11.6, U5.12
GPIO10: J11.5, U5.13
GPIO11: J11.4, U5.14
GPIO12: J11.3, U5.15
GPIO13: J15.6, U7.12
GPIO14: J15.5, U7.13
GPIO15: J15.4, U7.14
GPIO16: J15.3, U7.15
GPIO17: J19.6, U9.12
GPIO18: J19.5, U9.13
GPIO19: J19.4, U9.14
GPIO20: J19.3, U9.15
GPIO21: J23.6, U11.12
GPIO22: J23.5, U11.13
GPIO23: J23.4, U11.14
GPIO24: J23.3, U11.15
GPIO25: J27.6, U13.12
GPIO26: J27.5, U13.13
GPIO27: J27.4, U13.14
GPIO28: J27.3, U13.15
GPIO29: J31.6, U15.12
GPIO30: J31.5, U15.13
GPIO31: J31.4, U15.14
GPIO32: J31.3, U15.15
GPIO33: J35.6, U17.12
GPIO34: J35.5, U17.13
GPIO35: J35.4, U17.14
GPIO36: J35.3, U17.15
unnamed: C1.1, E1.ANT, L1.2
unnamed: D2.A, R3.1
unnamed: J3.B5, R1.2
unnamed: J3.A5, R2.2
unnamed: D1.1, J3.A6, J3.B6
unnamed: D2.C, PWR.2
unnamed: D1.3, J3.A7, J3.B7
unnamed: C6.1, C8.1, R5.1
unnamed: C5.1, C6.2, J5.FEED
unnamed: C9.1, L1.1, R4.2
unnamed: C7.1, U2.4
unnamed: D3.6, U1.20
unnamed: D3.4, U1.21
unnamed: R6.2, U2.2
unnamed: C10.1, E2.ANT, L2.2
unnamed: J4.B5, R8.2
unnamed: J4.A5, R9.2
unnamed: D4.1, J4.A6, J4.B6
unnamed: D4.3, J4.A7, J4.B7
unnamed: C15.1, C17.1, R12.1
unnamed: C14.1, C15.2, J6.FEED
unnamed: C18.1, L2.1, R11.2
unnamed: C16.1, U4.4
unnamed: D6.6, U3.20
unnamed: D6.4, U3.21
unnamed: D5.A, R10.1
unnamed: D5.C, PWR1.2
unnamed: R13.2, U4.2
unnamed: C19.1, E3.ANT, L3.2
unnamed: J9.B5, R15.2
unnamed: J9.A5, R16.2
unnamed: D7.1, J9.A6, J9.B6
unnamed: D7.3, J9.A7, J9.B7
unnamed: C24.1, C26.1, R19.1
unnamed: C23.1, C24.2, J10.FEED
unnamed: C27.1, L3.1, R18.2
unnamed: C25.1, U6.4
unnamed: D9.6, U5.20
unnamed: D9.4, U5.21
unnamed: D8.A, R17.1
unnamed: D8.C, PWR2.2
unnamed: R20.2, U6.2
unnamed: C28.1, E4.ANT, L4.2
unnamed: J13.B5, R22.2
unnamed: J13.A5, R23.2
unnamed: D10.1, J13.A6, J13.B6
unnamed: D10.3, J13.A7, J13.B7
unnamed: C33.1, C35.1, R26.1
unnamed: C32.1, C33.2, J14.FEED
unnamed: C36.1, L4.1, R25.2
unnamed: C34.1, U8.4
unnamed: D12.6, U7.20
unnamed: D12.4, U7.21
unnamed: D11.A, R24.1
unnamed: D11.C, PWR3.2
unnamed: R27.2, U8.2
unnamed: C37.1, E5.ANT, L5.2
unnamed: J17.B5, R29.2
unnamed: J17.A5, R30.2
unnamed: D13.1, J17.A6, J17.B6
unnamed: D13.3, J17.A7, J17.B7
unnamed: C42.1, C44.1, R33.1
unnamed: C41.1, C42.2, J18.FEED
unnamed: C45.1, L5.1, R32.2
unnamed: C43.1, U10.4
unnamed: D15.6, U9.20
unnamed: D15.4, U9.21
unnamed: D14.A, R31.1
unnamed: D14.C, PWR4.2
unnamed: R34.2, U10.2
unnamed: C46.1, E6.ANT, L6.2
unnamed: J21.B5, R36.2
unnamed: J21.A5, R37.2
unnamed: D16.1, J21.A6, J21.B6
unnamed: D16.3, J21.A7, J21.B7
unnamed: C51.1, C53.1, R40.1
unnamed: C50.1, C51.2, J22.FEED
unnamed: C54.1, L6.1, R39.2
unnamed: C52.1, U12.4
unnamed: D18.6, U11.20
unnamed: D18.4, U11.21
unnamed: D17.A, R38.1
unnamed: D17.C, PWR5.2
unnamed: R41.2, U12.2
unnamed: C55.1, E7.ANT, L7.2
unnamed: J25.B5, R43.2
unnamed: J25.A5, R44.2
unnamed: D19.1, J25.A6, J25.B6
unnamed: D19.3, J25.A7, J25.B7
unnamed: C60.1, C62.1, R47.1
unnamed: C59.1, C60.2, J26.FEED
unnamed: C63.1, L7.1, R46.2
unnamed: C61.1, U14.4
unnamed: D21.6, U13.20
unnamed: D21.4, U13.21
unnamed: D20.A, R45.1
unnamed: D20.C, PWR6.2
unnamed: R48.2, U14.2
unnamed: C64.1, E8.ANT, L8.2
unnamed: J29.B5, R50.2
unnamed: J29.A5, R51.2
unnamed: D22.1, J29.A6, J29.B6
unnamed: D22.3, J29.A7, J29.B7
unnamed: C69.1, C71.1, R54.1
unnamed: C68.1, C69.2, J30.FEED
unnamed: C72.1, L8.1, R53.2
unnamed: C70.1, U16.4
unnamed: D24.6, U15.20
unnamed: D24.4, U15.21
unnamed: D23.A, R52.1
unnamed: D23.C, PWR7.2
unnamed: R55.2, U16.2
unnamed: C73.1, E9.ANT, L9.2
unnamed: J33.B5, R57.2
unnamed: J33.A5, R58.2
unnamed: D25.1, J33.A6, J33.B6
unnamed: D25.3, J33.A7, J33.B7
unnamed: C78.1, C80.1, R61.1
unnamed: C77.1, C78.2, J34.FEED
unnamed: C81.1, L9.1, R60.2
unnamed: C79.1, U18.4
unnamed: D27.6, U17.20
unnamed: D27.4, U17.21
unnamed: D26.A, R59.1
unnamed: D26.C, PWR8.2
unnamed: R62.2, U18.2
RF: R4.1, R5.2, U1.39
RF1: R11.1, R12.2, U3.39
RF2: R18.1, R19.2, U5.39
RF3: R25.1, R26.2, U7.39
RF4: R32.1, R33.2, U9.39
RF5: R39.1, R40.2, U11.39
RF6: R46.1, R47.2, U13.39
RF7: R53.1, R54.2, U15.39
RF8: R60.1, R61.2, U17.39
RX: D3.3, S1.5
RX1: D6.3, S2.5
RX2: D9.3, S3.5
RX3: D12.3, S4.5
RX4: D15.3, S5.5
RX5: D18.3, S6.5
RX6: D21.3, S7.5
RX7: D24.3, S8.5
RX8: D27.3, S9.5
RX_SER: J2.4, S1.4
RX_SER1: J8.4, S2.4
RX_SER2: J12.4, S3.4
RX_SER3: J16.4, S4.4
RX_SER4: J20.4, S5.4
RX_SER5: J24.4, S6.4
RX_SER6: J28.4, S7.4
RX_SER7: J32.4, S8.4
RX_SER8: J36.4, S9.4
RX_USB: R6.1, R7.2, S1.6
RX_USB1: R13.1, R14.2, S2.6
RX_USB2: R20.1, R21.2, S3.6
RX_USB3: R27.1, R28.2, S4.6
RX_USB4: R34.1, R35.2, S5.6
RX_USB5: R41.1, R42.2, S6.6
RX_USB6: R48.1, R49.2, S7.6
RX_USB7: R55.1, R56.2, S8.6
RX_USB8: R62.1, R63.2, S9.6
SHLD: J3.SHLD1, J3.SHLD2, J3.SHLD3, J3.SHLD4, SHLD.2
SHLD1: J4.SHLD1, J4.SHLD2, J4.SHLD3, J4.SHLD4, SHLD1.2
SHLD2: J9.SHLD1, J9.SHLD2, J9.SHLD3, J9.SHLD4, SHLD2.2
SHLD3: J13.SHLD1, J13.SHLD2, J13.SHLD3, J13.SHLD4, SHLD3.2
SHLD4: J17.SHLD1, J17.SHLD2, J17.SHLD3, J17.SHLD4, SHLD4.2
SHLD5: J21.SHLD1, J21.SHLD2, J21.SHLD3, J21.SHLD4, SHLD5.2
SHLD6: J25.SHLD1, J25.SHLD2, J25.SHLD3, J25.SHLD4, SHLD6.2
SHLD7: J29.SHLD1, J29.SHLD2, J29.SHLD3, J29.SHLD4, SHLD7.2
SHLD8: J33.SHLD1, J33.SHLD2, J33.SHLD3, J33.SHLD4, SHLD8.2
TX: D3.1, S1.2
TX1: D6.1, S2.2
TX2: D9.1, S3.2
TX3: D12.1, S4.2
TX4: D15.1, S5.2
TX5: D18.1, S6.2
TX6: D21.1, S7.2
TX7: D24.1, S8.2
TX8: D27.1, S9.2
TX_SER: J2.5, S1.1
TX_SER1: J8.5, S2.1
TX_SER2: J12.5, S3.1
TX_SER3: J16.5, S4.1
TX_SER4: J20.5, S5.1
TX_SER5: J24.5, S6.1
TX_SER6: J28.5, S7.1
TX_SER7: J32.5, S8.1
TX_SER8: J36.5, S9.1
TX_USB: S1.3, U2.3
TX_USB1: S2.3, U4.3
TX_USB2: S3.3, U6.3
TX_USB3: S4.3, U8.3
TX_USB4: S5.3, U10.3
TX_USB5: S6.3, U12.3
TX_USB6: S7.3, U14.3
TX_USB7: S8.3, U16.3
TX_USB8: S9.3, U18.3
USB_N: D1.4, U2.6
USB_N1: D4.4, U4.6
USB_N2: D7.4, U6.6
USB_N3: D10.4, U8.6
USB_N4: D13.4, U10.6
USB_N5: D16.4, U12.6
USB_N6: D19.4, U14.6
USB_N7: D22.4, U16.6
USB_N8: D25.4, U18.6
USB_P: D1.6, U2.5
USB_P1: D4.6, U4.5
USB_P2: D7.6, U6.5
USB_P3: D10.6, U8.5
USB_P4: D13.6, U10.5
USB_P5: D16.6, U12.5
USB_P6: D19.6, U14.5
USB_P7: D22.6, U16.5
USB_P8: D25.6, U18.5
VCC: J2.3, VIN_SEL.1
VCC1: J8.3, VIN_SEL1.1
VCC2: J12.3, VIN_SEL2.1
VCC3: J16.3, VIN_SEL3.1
VCC4: J20.3, VIN_SEL4.1
VCC5: J24.3, VIN_SEL5.1
VCC6: J28.3, VIN_SEL6.1
VCC7: J32.3, VIN_SEL7.1
VCC8: J36.3, VIN_SEL8.1
VIN: C2.1, C4.1, J1.2, U1.16, U1.17, VIN_SEL.2
VIN1: C11.1, C13.1, J7.2, U3.16, U3.17, VIN_SEL1.2
VIN2: C20.1, C22.1, J11.2, U5.16, U5.17, VIN_SEL2.2
VIN3: C29.1, C31.1, J15.2, U7.16, U7.17, VIN_SEL3.2
VIN4: C38.1, C40.1, J19.2, U9.16, U9.17, VIN_SEL4.2
VIN5: C47.1, C49.1, J23.2, U11.16, U11.17, VIN_SEL5.2
VIN6: C56.1, C58.1, J27.2, U13.16, U13.17, VIN_SEL6.2
VIN7: C65.1, C67.1, J31.2, U15.16, U15.17, VIN_SEL7.2
VIN8: C74.1, C76.1, J35.2, U17.16, U17.17, VIN_SEL8.2
VOUT: D3.5, J1.8, R3.2, U1.10
VOUT1: D6.5, J7.8, R10.2, U3.10
VOUT2: D9.5, J11.8, R17.2, U5.10
VOUT3: D12.5, J15.8, R24.2, U7.10
VOUT4: D15.5, J19.8, R31.2, U9.10
VOUT5: D18.5, J23.8, R38.2, U11.10
VOUT6: D21.5, J27.8, R45.2, U13.10
VOUT7: D24.5, J31.8, R52.2, U15.10
VOUT8: D27.5, J35.8, R59.2, U17.10
V_USB: C3.1, D1.5, J3.VBUS1, J3.VBUS2, U2.16, VIN_SEL.3
V_USB1: C12.1, D4.5, J4.VBUS1, J4.VBUS2, U4.16, VIN_SEL1.3
V_USB2: C21.1, D7.5, J9.VBUS1, J9.VBUS2, U6.16, VIN_SEL2.3
V_USB3: C30.1, D10.5, J13.VBUS1, J13.VBUS2, U8.16, VIN_SEL3.3
V_USB4: C39.1, D13.5, J17.VBUS1, J17.VBUS2, U10.16, VIN_SEL4.3
V_USB5: C48.1, D16.5, J21.VBUS1, J21.VBUS2, U12.16, VIN_SEL5.3
V_USB6: C57.1, D19.5, J25.VBUS1, J25.VBUS2, U14.16, VIN_SEL6.3
V_USB7: C66.1, D22.5, J29.VBUS1, J29.VBUS2, U16.16, VIN_SEL7.3
V_USB8: C75.1, D25.5, J33.VBUS1, J33.VBUS2, U18.16, VIN_SEL8.3

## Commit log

2024-01-02 Initial design with M7E
    [SparkFun_Simultaneous_RFID_Reader_M7E.brd, SparkFun_Simultaneous_RFID_Reader_M7E.sch]
2024-01-02 Change VIN selection jumper
    Now uses a 3-way jumper to independently select USB, VCC from serial head, or just dedicated VIN pin
    [SparkFun_Simultaneous_RFID_Reader_M7E.brd, SparkFun_Simultaneous_RFID_Reader_M7E.sch]
2024-01-02 Change 3.3V net to VOUT
    The M7E internal regulator actually outputs 2.5V when idle
    [SparkFun_Simultaneous_RFID_Reader_M7E.brd, SparkFun_Simultaneous_RFID_Reader_M7E.sch]
2024-01-03 Fix CH340 power
    Can't be powered by VOUT, because the module outputs 2.5V while idle, which is too low for the CH340
    Now powered by VUSB. The only problem here is that the output voltage is based on VCC, so a voltage divider is used to make the output voltage ~3.3V
    [SparkFun_Simultaneous_RFID_Reader_M7E.brd, SparkFun_Simultaneous_RFID_Reader_M7E.sch]
2024-01-03 Add PROD_ID of M7E
    [SparkFun_Simultaneous_RFID_Reader_M7E.brd, SparkFun_Simultaneous_RFID_Reader_M7E.sch]
2024-01-04 Design review updates
    Add polygons to better fan out USB traces from ESD diode pads
    Nudge R3 away from VOUT pad
    Add VOUT range to schematic
    Swap power LED and resistor for new version
    Move via out of VO silk label
    Nudge USB traces to get better GND pour around C7
    [SparkFun_Simultaneous_RFID_Reader_M7E.brd, SparkFun_Simultaneous_RFID_Reader_M7E.sch]
2024-01-04 Design review update
    Actually update the power LED and resistor this time
    Actually move the via on the VO silk this time
    Actually nudge USB traces to get better GND pour around C7 this time
    [SparkFun_Simultaneous_RFID_Reader_M7E.brd, SparkFun_Simultaneous_RFID_Reader_M7E.sch]
2024-01-05 Design review updates
    Update section titles in schematic
    Remote DTR and CTS silk from serial header
    Add ordering instructions
    Update measures
    [SparkFun_Simultaneous_RFID_Reader_M7E.brd, SparkFun_Simultaneous_RFID_Reader_M7E.sch]
2024-01-05 Fix VO silk label
    [SparkFun_Simultaneous_RFID_Reader_M7E.brd]
2024-01-05 Add v10 panel files
    [SparkFun_Simultaneous_RFID_Reader_M7E-Panel.GBL, SparkFun_Simultaneous_RFID_Reader_M7E-Panel.GBO, SparkFun_Simultaneous_RFID_Reader_M7E-Panel.GBP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]
2024-03-28 Fix DNP components and PROD_ID values
    [SparkFun_Simultaneous_RFID_Reader_M7E-Panel.brd, SparkFun_Simultaneous_RFID_Reader_M7E.brd, SparkFun_Simultaneous_RFID_Reader_M7E.sch]
2024-04-09 Docs photos update
    Adding revised overview photos, new assembly photos, and minor updates to hardware overview, assembly, and reader assistant sections.
2024-05-16 Docs Update
    Adding product showcase embed and minor edits to assembly & troubleshooting.

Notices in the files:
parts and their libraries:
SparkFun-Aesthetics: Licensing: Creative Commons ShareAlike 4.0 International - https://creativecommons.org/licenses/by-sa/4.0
